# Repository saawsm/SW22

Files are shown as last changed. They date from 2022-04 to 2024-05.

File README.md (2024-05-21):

# SW22 - A modular E-Stim

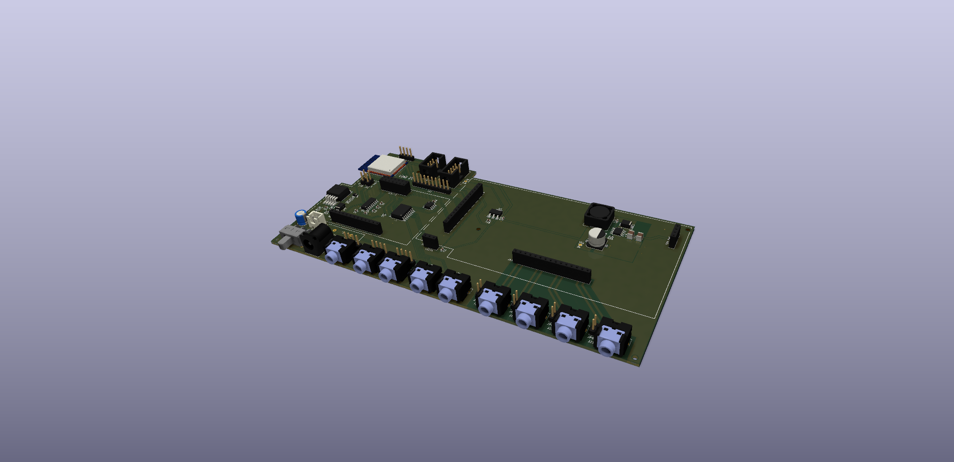
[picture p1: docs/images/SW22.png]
SW22


---
**The SW22 is deprecated. See the [SW32 E-Stim](https://github.com/saawsm/SW32) for a better alternative.**

*This project is a work in-progress. Changes to the design might occur. Order PCBs at your own risk..*

---

## About
The SW22 is a modular E-Stim box based on the [ZC95](https://github.com/CrashOverride85/zc95) and the [WT-312](https://github.com/WendyTeslaburger/WT-312). 
It has a similar form factor and output design to the MK312-BT (which in turn is a clone of the ET-312B).

An <abbr title="ESP32-WROOM-32">ESP32</abbr> module is used for high level control (front panel controls, display, Bluetooth audio, etc) of the device, while an RP2040 microcontroller (RPi Pico) is used as a co-processor for pulse/routine generation (taking advantage of [PIO](https://raspberrypi.github.io/pico-sdk-doxygen/group__hardware__pio.html#details)). The firmware is open source and written in C.

Compared to the MK312-BT, it has two extra output channels, four auxiliary inputs, and four triggers. 

## Features
* Bluetooth A2DP*
* RS232 front panel serial
* 2x TRS 3.5mm Aux channels with expansion board support (e.g. Stereo Audio + Mono Microphone, RS232 Remote)
* 2x TRS 3.5mm Trigger channels
* Tri polar (+, GND, -) output channel support
* Modular output drivers per channel (Think: Sparkfun, Adafruit, etc.) incl. modular driver board.
* Individual channel sensing via quad 12-bit ADC
* 1.8" Color TFT display
* Support for an internal 0.96" I2C OLED display (e.g. debugging/testing)
* 256kb EEPROM for configuration
* Battery voltage monitoring
* Charge sense (Barrel jack voltage monitoring)

## Overview
The SW22 consists of following PCBs:
* Front Panel Cover - No traces, just the cosmetic front panel with text. Could be 3D printed or laser cut.
* Front Panel - I2C based expansion board with 4x POTs with associated ADC, 1x rotary encoder, 4x tactile buttons, 1x buzzer, and 8x addressable RGB LEDs.
* Base Board - Provides system power, battery charging, expansion, Bluetooth, front panel interface, and general control.
* Driver Board - Provides low-level control over channel output modules.
* Output Modules - Generates the E-Stim for each channel. A module per channel, controlled by the driver board. 
* Expansion Module (Optional) - Allows advanced configuration of Aux channels (e.g. Audio+Microphone)

The main reason for having modular PCBs is for flexibility and long term cost saving. Most of the cost and time that is involved in the project is the firmware, case, display, controls, etc. So being able to reuse parts when changing the design (e.g. new output modules, driver board, etc) should help keep time and cost down.

Additionally, the SW22 was designed with the front panel and display being optional accessories. Anything that can be achieved on the front panel, can be done via Bluetooth/WiFi. The driver board can be used as a standalone module (Think: Sparkfun, Adafruit, etc.).

## Build Notes
The majority of this build is SMT. I have tried to keep parts large enough (0603 and above) for manual pick and place. However, for a few components, no alternative was available (e.g. Driver board uses MSOP/VSSOP packages).

Most SMD components used are available from Mouser and LCSC. Front panel components being mostly available at places that aren't LCSC (pots, encoders, audio jacks, etc).

Some components have a thermal pad that will require a reflow oven or using hot air reflow soldering.

## [Schematics](schematics/)

## [Gerbers](gerbers/)
Gerbers are created for use with JLCPCB. P&P POS files untested/missing (since I assemble the PCBs myself).

## Firmware
The firmware is open source and written in C. You can find the source code in the [swef](https://github.com/saawsm/swef) and [swx](https://github.com/saawsm/swx) repositories.

`swef` and `swx` don't support SPI used by the SW22 for connection between the base and driver boards. Basic functionality requires adding additional bodge wires (SDA and SCL) between the base and driver boards.

This change was done to simplify communications and to prepare for the successor [SW32](https://github.com/saawsm/SW32) box.

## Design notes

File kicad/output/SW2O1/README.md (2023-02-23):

## SW2O1 - Single Channel Output Module

This is a single channel E-Stim output module. It tries to mimic the output stage of the well-known Erostec ET312, or better, the MK-312.

The design of this module was based on the [WT-312](https://github.com/WendyTeslaburger/WT-312).

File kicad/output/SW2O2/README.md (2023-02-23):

## SW2O2 - Single Channel Output Module

A single channel E-Stim output module. It tries to mimic the output stage of the well-known Erostec ET312, or better, the MK-312.

This module is functionally the same as the SW2O1 but uses a TO-220 package for the power limiting circuit. Allowing for the use of the IRF9Z24 P-Fet used in the MK-312.

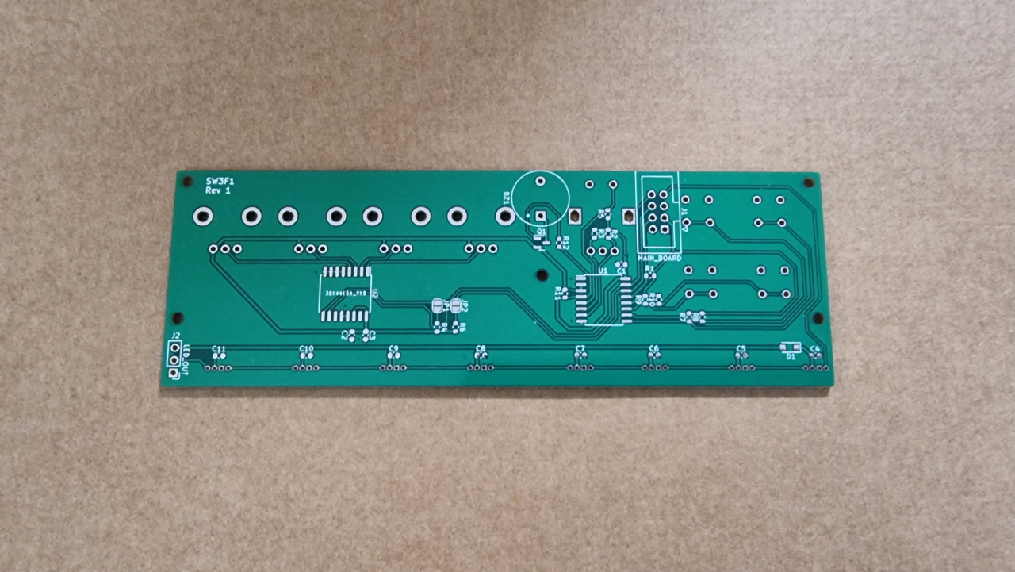
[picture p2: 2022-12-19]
docs/images/SW2F1_unpopulated_back.png

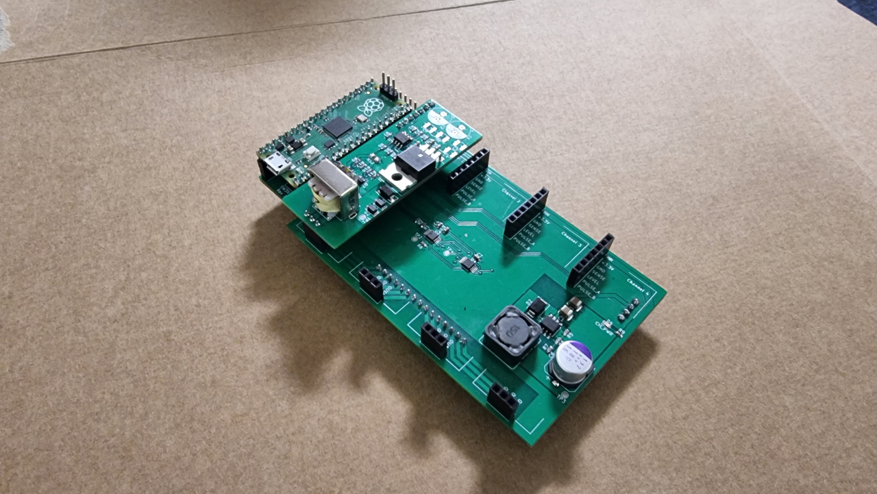
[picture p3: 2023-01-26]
docs/images/SW2X1_stacked.png

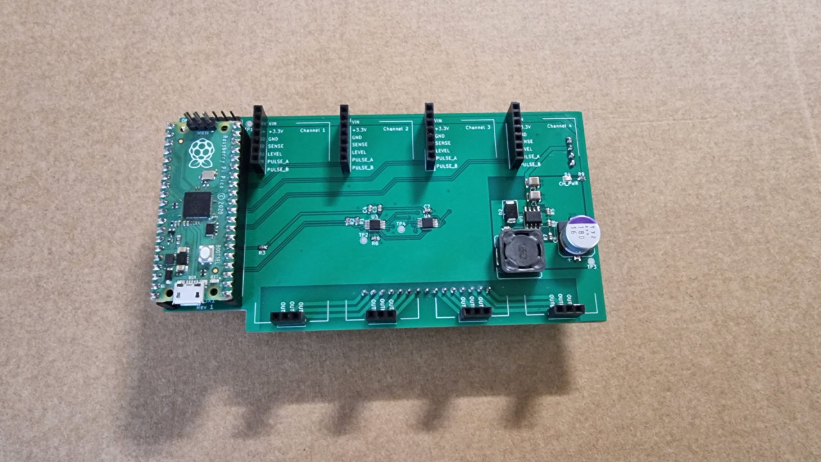
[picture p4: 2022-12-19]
docs/images/SW2X1_populated_pico.png

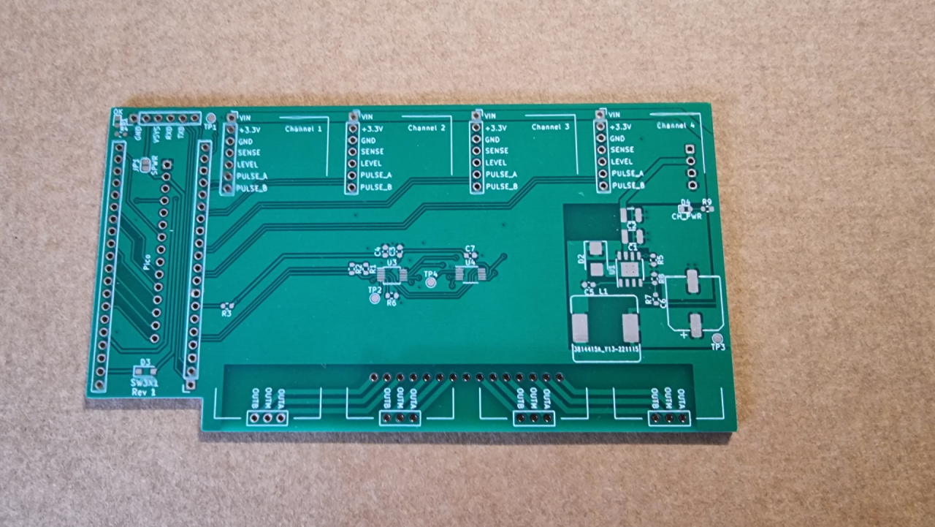
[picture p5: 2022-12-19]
docs/images/SW2X1_unpopulated.png

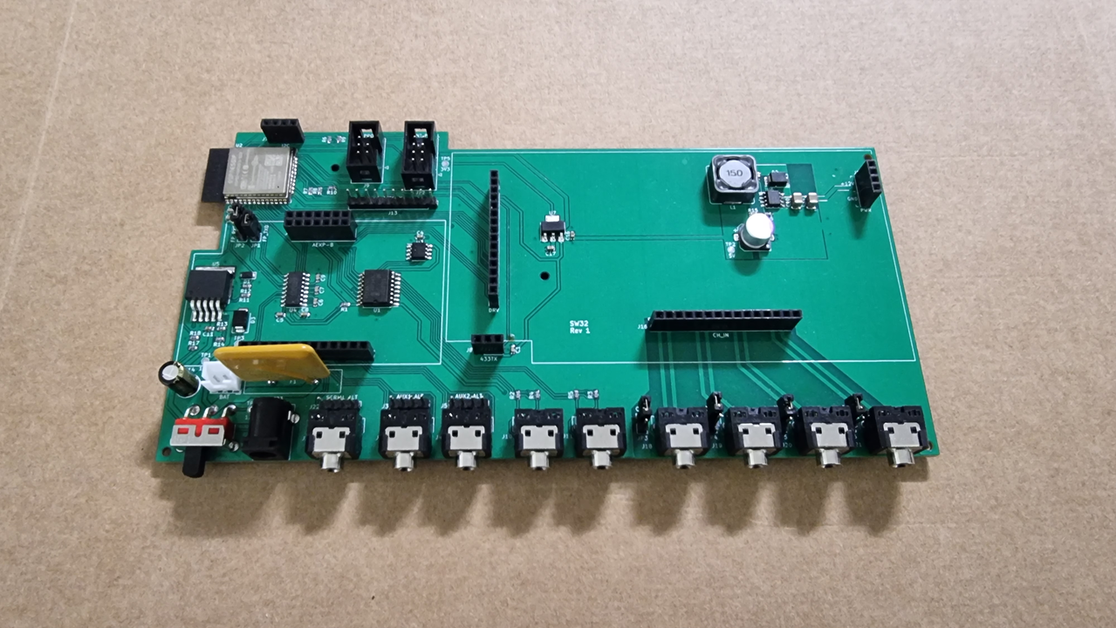
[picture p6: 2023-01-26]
docs/images/SW22_populated.png

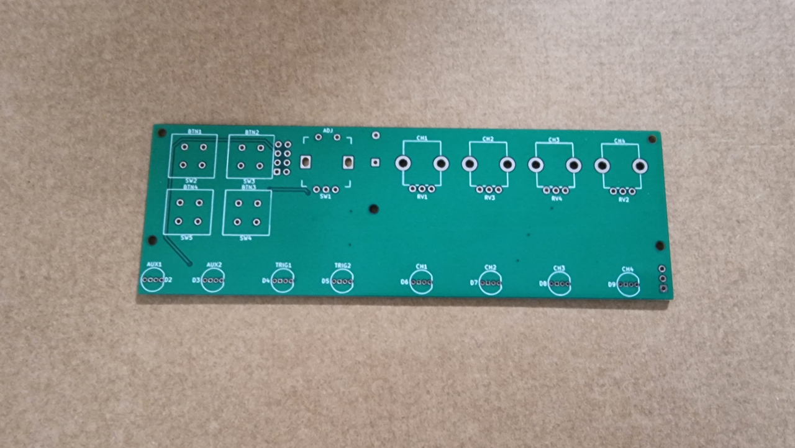
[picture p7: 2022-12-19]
docs/images/SW2F1_unpopulated_front.png

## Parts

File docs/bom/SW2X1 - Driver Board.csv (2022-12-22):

Ref | Qty | Value | Description | MPN | MOUSER | LCSC
C1, C2 | 2 | 10uF | Unpolarized capacitor | CL32A106KBJNNNE | 187-CL32A106KBJNNNE | C380537
C3 | 1 | 10uF | Unpolarized capacitor, small symbol | CL10A106MA8NRNC | 187-CL10A106MA8NRNC | C96446
C4, C7 | 2 | 100nF | Unpolarized capacitor, small symbol | CL10B104KB8NNNC | 187-CL10B104KB8NNNC | C1591
C5 | 1 | 10nF | Unpolarized capacitor | CL10B103KB8NNNC | 187-CL10B103KB8NNNC | C1589
C6 | 1 | 180uF | Polarized capacitor | 16SVP180MX | 667-16SVP180MX | C236288
D1 | 1 | OK | Light emitting diode | 150060VS75000 | 710-150060VS75000
D2 | 1 | SSB44-E3 | Schottky diode | SSB44-E3/52T | 625-SSB44-E3 | C466999
D3 | 1 | SS24FL | Schottky diode | SS24FL | 512-SS24FL | C894433
D4 | 1 | CH_PWR | Light emitting diode | 150060BS75000 | 710-150060BS75000
J1 | 1 | SERIAL (3v3) | Generic connector, single row, 01x06, script generated (kicad-library-utils/schlib/autogen/connector/)
J2 | 1 | PWR | Generic connector, single row, 01x04, script generated (kicad-library-utils/schlib/autogen/connector/)
J3 | 1 | CONTROL | Generic connector, single row, 01x15, script generated (kicad-library-utils/schlib/autogen/connector/)
J4 | 1 | Channel 1 | Dual Channel Output Driver Module
J5 | 1 | Channel 2 | Dual Channel Output Driver Module
J6 | 1 | Channel 3 | Dual Channel Output Driver Module
J7 | 1 | Channel 4 | Dual Channel Output Driver Module
J8 | 1 | CH_OUT | Generic connector, single row, 01x15, script generated (kicad-library-utils/schlib/autogen/connector/)
L1 | 1 | 15uH | Inductor with ferrite core | SRR1260-150M | 652-SRR1260-150M | C2041333
R1, R2, R9 | 3 | 4.7K | Resistor | RC0603FR-074K7L | 603-RC0603FR-074K7L | C99782
R3, R6, R7 | 3 | 10K | Resistor | RC0603FR-0710KL | 603-RC0603FR-0710KL | C98220
R4, R8 | 2 | 1.5K | Resistor | RC0603FR-071K5L | 603-RC0603FR-071K5L | C114668
R5 | 1 | 100K | Resistor | RC0603FR-07100KL | 603-RC0603FR-07100KL | C14675
U1 | 1 | TPS5430DDA | 3A, Step Down Swift Converter, Adjustable Output Voltage, 5.5-36V Input Voltage, PowerSO-8 | TPS5430DDAR | 595-TPS5430DDAR | C9864
U2 | 1 | Pico |  | RASPBERRY PI PICO (UNSOLDERED) | 713-102110537
U3 | 1 | MCP4728 | 12-bit digital to analog converter, quad output, 2.048V internal reference, integrated EEPROM, I2C interface | MCP4728-E/UN | 579-MCP4728-E/UN | C108207
U4 | 1 | ADS1015 | Ultra-Small, Low-Power, I2C-Compatible, 3.3-kSPS, 12-Bit ADCs With Internal Reference, Oscillator, and Programmable Comparator, VSSOP-10 | ADS1015IDGSR | 595-ADS1015IDGSR | C193969

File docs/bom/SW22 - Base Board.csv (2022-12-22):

Ref | Qty | Value | Description | MPN | MOUSER | LCSC
C1, C3, C4, C5, C6, C7, C8, C9, C18 | 9 | 100nF | Unpolarized capacitor, small symbol | CL10B104KB8NNNC | 187-CL10B104KB8NNNC | C1591
C2, C16, C17 | 3 | 10uF | Unpolarized capacitor | CL10A106MA8NRNC | 187-CL10A106MA8NRNC | C96446
C10, C12 | 2 | 10uF | Unpolarized capacitor | CL32A106KBJNNNE | 187-CL32A106KBJNNNE | C380537
C11 | 1 | 470nF | Unpolarized capacitor | CL10A474KB8NNNC | 187-CL10A474KB8NNNC | C170149
C13 | 1 | 10nF | Unpolarized capacitor | CL10B103KB8NNNC | 187-CL10B103KB8NNNC | C1589
C14 | 1 | 100uF | Polarized capacitor | EEU-FM1E101 | 667-EEU-FM1E101 | C1579509
C15 | 1 | 270uF | Polarized capacitor | 16SVPF270M | 667-16SVPF270M | C136278
D1 | 1 | SS24FL | Schottky diode | SS24FL | 512-SS24FL | C894433
D2, D3 | 2 | SSB44-E3 | Schottky diode | SSB44-E3/52T | 625-SSB44-E3 | C466999
D4 | 1 | PWR | Light emitting diode | 150060VS75000 | 710-150060VS75000
F1 | 1 | 2A | Resettable fuse, polymeric positive temperature coefficient | LVR200S-240 | 650-LVR200S-240 | C1562345
J1 | 1 | AEXP-B | Generic connector, double row, 02x07, odd/even pin numbering scheme (row 1 odd numbers, row 2 even numbers), script generated (kicad-library-utils/schlib/autogen/connector/)
J2 | 1 | AUX1 | Audio Jack, 3 Poles (Stereo / TRS), Switched TR Poles (Normalling) | STX-3100-5N | 806-STX-3100-5N
J3 | 1 | AUX1_ALT | Generic connector, single row, 01x04, script generated (kicad-library-utils/schlib/autogen/connector/)
J4 | 1 | AUX2 | Audio Jack, 3 Poles (Stereo / TRS), Switched TR Poles (Normalling) | STX-3100-5N | 806-STX-3100-5N
J5 | 1 | AUX2_ALT | Generic connector, single row, 01x04, script generated (kicad-library-utils/schlib/autogen/connector/)
J6 | 1 | AEXP-A | Generic connector, single row, 01x13, script generated (kicad-library-utils/schlib/autogen/connector/)
J7 | 1 | I2C | Generic connector, single row, 01x04, script generated (kicad-library-utils/schlib/autogen/connector/)
J8 | 1 | 433TX | Generic connector, single row, 01x03, script generated (kicad-library-utils/schlib/autogen/connector/)
J9 | 1 | PROG | Generic connector, double row, 02x03, odd/even pin numbering scheme (row 1 odd numbers, row 2 even numbers), script generated (kicad-library-utils/schlib/autogen/connector/)
J10 | 1 | TRG1 | Audio Jack, 3 Poles (Stereo / TRS), Switched TR Poles (Normalling) | STX-3100-5N | 806-STX-3100-5N
J11 | 1 | TRG2 | Audio Jack, 3 Poles (Stereo / TRS), Switched TR Poles (Normalling) | STX-3100-5N | 806-STX-3100-5N
J12 | 1 | FRONT_PANEL | Generic connector, double row, 02x04, odd/even pin numbering scheme (row 1 odd numbers, row 2 even numbers), script generated (kicad-library-utils/schlib/autogen/connector/)
J13 | 1 | DISPLAY | Generic connector, single row, 01x10, script generated (kicad-library-utils/schlib/autogen/connector/)
J14 | 1 | DRV | Generic connector, single row, 01x15, script generated (kicad-library-utils/schlib/autogen/connector/)
J15 | 1 | PWR | Generic connector, single row, 01x04, script generated (kicad-library-utils/schlib/autogen/connector/)
J16 | 1 | CH_IN | Generic connector, single row, 01x15, script generated (kicad-library-utils/schlib/autogen/connector/)
J17 | 1 | SERIAL | Audio Jack, 3 Poles (Stereo / TRS), Switched TR Poles (Normalling) | STX-3100-5N | 806-STX-3100-5N
J18 | 1 | CH1 | Audio Jack, 3 Poles (Stereo / TRS), Switched TR Poles (Normalling) | STX-3100-5N | 806-STX-3100-5N
J19 | 1 | CH2 | Audio Jack, 3 Poles (Stereo / TRS), Switched TR Poles (Normalling) | STX-3100-5N | 806-STX-3100-5N
J20 | 1 | CH3 | Audio Jack, 3 Poles (Stereo / TRS), Switched TR Poles (Normalling) | STX-3100-5N | 806-STX-3100-5N
J21 | 1 | CH4 | Audio Jack, 3 Poles (Stereo / TRS), Switched TR Poles (Normalling) | STX-3100-5N | 806-STX-3100-5N
J22 | 1 | SERIAL_ALT | Generic connector, single row, 01x04, script generated (kicad-library-utils/schlib/autogen/connector/)
J23 | 1 | PWR | DC Barrel Jack with an internal switch | PJ-102AH | 490-PJ-102AH
J24 | 1 | BAT | Generic screw terminal, single row, 01x02, script generated (kicad-library-utils/schlib/autogen/connector/)
JP1 | 1 | FP_TXD | Jumper, 2-pole, closed/bridged
JP2 | 1 | FP_RXD | Jumper, 2-pole, closed/bridged
JP3 | 1 | CT1 | Jumper, 2-pole, open
JP4 | 1 | CT2 | Jumper, 2-pole, open
JP5 | 1 | CT3 | Jumper, 2-pole, open
JP6 | 1 | CT4 | Jumper, 2-pole, open
L1 | 1 | 15uH | Inductor with ferrite core | SRR1260-150M | 652-SRR1260-150M | C2041333
R1, R2, R3, R4, R5, R7, R8, R10, R12, R13, R15, R19 | 12 | 10K | Resistor, small symbol | RC0603FR-0710KL | 603-RC0603FR-0710KL | C98220
R6, R9, R18 | 3 | 4.7K | Resistor | RC0603FR-074K7L | 603-RC0603FR-074K7L | C99782
R11 | 1 | 100K | Resistor | RC0603FR-07100KL | 603-RC0603FR-07100KL | C14675
R14 | 1 | 1K | Resistor | RC0603FR-071KL | 603-RC0603FR-071KL | C22548
R16 | 1 | 3.24K | Resistor | RC0603FR-073K24L | 603-RC0603FR-073K24L | C273779
R17 | 1 | 27K | Resistor | RC0603FR-0727KL | 603-RC0603FR-0727KL | C114614
R20 | 1 | 1.5k | Resistor | RC0603FR-071K5L | 603-RC0603FR-071K5L | C114668
SW1 | 1 | PWR | Switch, single pole double throw | 500SSP1S2M6QEA | 612-500-A261
U1 | 1 | PCF8574 | 8 Bit Port/Expander to I2C Bus, DIP/SOIC-16 | PCF8574T/3,512 | 771-PCF85T3512 | C1522621
U2 | 1 | ESP32-WROOM-32D | RF Module, ESP32-D0WD SoC, Wi-Fi 802.11b/g/n, Bluetooth, BLE, 32-bit, 2.7-3.6V, onboard antenna, SMD | ESP32-WROOM-32D-N16
U3 | 1 | CAT24C256 | 256 kb CMOS Serial EEPROM, DIP-8/SOIC-8/TSSOP-8/DFN-8 | CAT24C256WI-GT3 | 698-CAT24C256WI-GT3 | C79987
U4 | 1 | SP3232 | Dual RS232 driver/receiver, 5V supply, 120kb/s, 0C-70C | SP3232EEN-L/TR | 701-SP3232EEN-L/TR | C9378
U5 | 1 | LM2941 | LM2941x 1-A Low Dropout Adjustable Regulator | LM2941CSX/NOPB | 926-LM2941CSX/NOPB | C512759
U6 | 1 | TPS5430DDA | 3A, Step Down Swift Converter, Adjustable Output Voltage, 5.5-36V Input Voltage, PowerSO-8 | TPS5430DDAR | 595-TPS5430DDAR | C9864
U7 | 1 | NCP1117LP | 1A Low drop-out regulator, Fixed Output 3.3V, SOT-223 | NCP1117LPST33T3G | 863-NCP1117LPST33T3G | C146799

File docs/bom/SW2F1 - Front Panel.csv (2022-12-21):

Ref | Qty | Value | Description | MPN | MOUSER | LCSC
BZ1 | 1 | Buzzer | Buzzer, polarized | IE122303-1 | 497-IE122303-1
C1, C2, C4, C5, C6, C7, C8, C9, C10, C11 | 10 | 100nF | Unpolarized capacitor, small symbol | CL10B104KB8NNNC | 187-CL10B104KB8NNNC | C1591
C3 | 1 | 10uF | Unpolarized capacitor, small symbol | CL10A106MA8NRNC | 187-CL10A106MA8NRNC | C96446
D1 | 1 | SS24FL | Schottky diode | SS24FL | 512-SS24FL | C894433
D2 | 1 | AUX1 |  | WS2812D-F5 |  | C190565
D3 | 1 | AUX2 |  | WS2812D-F5 |  | C190565
D4 | 1 | TRIG1 |  | WS2812D-F5 |  | C190565
D5 | 1 | TRIG2 |  | WS2812D-F5 |  | C190565
D6 | 1 | CH1 |  | WS2812D-F5 |  | C190565
D7 | 1 | CH2 |  | WS2812D-F5 |  | C190565
D8 | 1 | CH3 |  | WS2812D-F5 |  | C190565
D9 | 1 | CH4 |  | WS2812D-F5 |  | C190565
J1 | 1 | MAIN_BOARD | Generic connector, double row, 02x04, odd/even pin numbering scheme (row 1 odd numbers, row 2 even numbers), script generated (kicad-library-utils/schlib/autogen/connector/)
Q1 | 1 | DMG2301L-7 | P-MOSFET transistor, gate/source/drain | DMG2301L-7 | 621-DMG2301L-7 | C102619
R1, R2, R3, R4, R5, R6, R7, R8, R9, R10, R11 | 11 | 10K | Resistor, small symbol | RC0603FR-0710KL | 603-RC0603FR-0710KL | C98220
R12 | 1 | 100 | Resistor, small symbol | RC0603FR-07100RL | 603-RC0603FR-07100RL | C105588
RV1 | 1 | CH1 | Potentiometer | PTV09A-4020S-B103
RV2 | 1 | CH4 | Potentiometer | PTV09A-4020S-B103
RV3 | 1 | CH2 | Potentiometer | PTV09A-4020S-B103
RV4 | 1 | CH3 | Potentiometer | PTV09A-4020S-B103
SW1 | 1 | PEC11R-4215K-S0024 | Rotary encoder, dual channel, incremental quadrate outputs, with switch | PEC11R-4215K-S0024
SW2 | 1 | BTN1 | Push button switch, generic, two pins | D6C90F2LFS | 611-D6C90F2LFS
SW3 | 1 | BTN2 | Push button switch, generic, two pins | D6C90F2LFS | 611-D6C90F2LFS
SW4 | 1 | BTN3 | Push button switch, generic, two pins | D6C90F2LFS | 611-D6C90F2LFS
SW5 | 1 | BTN4 | Push button switch, generic, two pins | D6C90F2LFS | 611-D6C90F2LFS
U1 | 1 | PCF8574 | 8 Bit Port/Expander to I2C Bus, DIP/SOIC-16 | PCF8574T/3,512 | 771-PCF85T3512 | C1522621
U2 | 1 | PCF8591 | 4ch ADC, 1 DAC, I2C Bus Interface, DIP/SOIC-16 | PCF8591T/2,518 | 771-PCF8591TD-T | C8366

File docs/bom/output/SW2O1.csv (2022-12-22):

Ref | Qty | Value | Description | MPN | MOUSER | LCSC
C1, C2 | 2 | 470uF | Polarized capacitor, US symbol | 477CKE016M
C3, C4, C6, C7 | 4 | 22uF | Unpolarized capacitor | CL32A226KAJNNNE
C5, C9 | 2 | 100nF | Unpolarized capacitor | CL10B104KB8NNWC
C8 | 1 | 1uF | Unpolarized capacitor | CL10B105KA8NFNC
D1 | 1 | SML4746-E3/61 | Zener diode | SML4746-E3/61
D2, D3 | 2 | SS24FL | Schottky diode | SS24FL | 512-SS24FL | C894433
FB1 | 1 | 100 | Ferrite bead, small symbol | BLM18KG101TN1D
Q1 | 1 | NTF2955T1G | P-MOSFET transistor, gate/drain/source | NTF2955T1G
Q2, Q3 | 2 | DMN2041L | 6.4A Id, 20V Vds, N-Channel MOSFET, SOT-23 | DMN2041L
R1, R5, R6 | 3 | 10k | Resistor | RC0603FR-0710KL
R2, R9, R10 | 3 | 10K | Resistor | RC0603FR-0710KL
R3 | 1 | 2K | Resistor | RC0603FR-072KL
R4 | 1 | 1K | Resistor | RC0603FR-071KL
R7, R8 | 2 | 100K | Resistor | RC0603FR-07100KL
R11, R12 | 2 | 100 | Resistor | RC0603FR-07100RL
R13 | 1 | 0.1 | Resistor | ERJ-8BWFR100V
T1 | 1 | 42TL004-RC |  | 42TL004-RC
U2 | 1 | LM358ADT | Dual CMOS Rail-to-Rail Input and Output Operational Amplifier, DIP-8/SOIC-8, SSOP-8 | LM358ADT

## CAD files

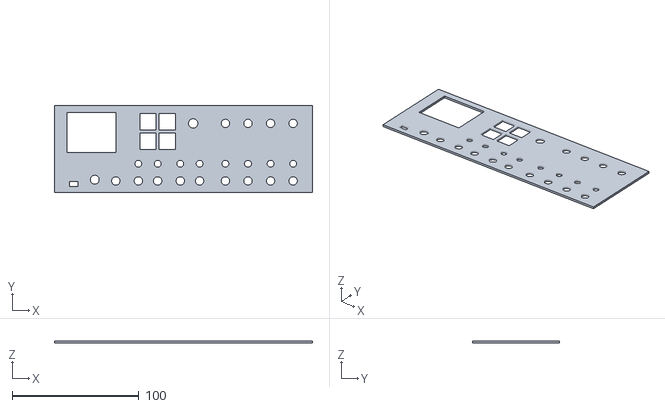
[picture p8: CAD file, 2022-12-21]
misc/SW2C1 - Front Cover.stl
203.2 x 68.6 x 1.60

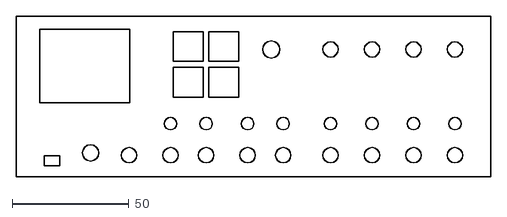
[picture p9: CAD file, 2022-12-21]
misc/SW2C1 - Front Cover-Edge_Cuts.dxf
203.2 x 68.6

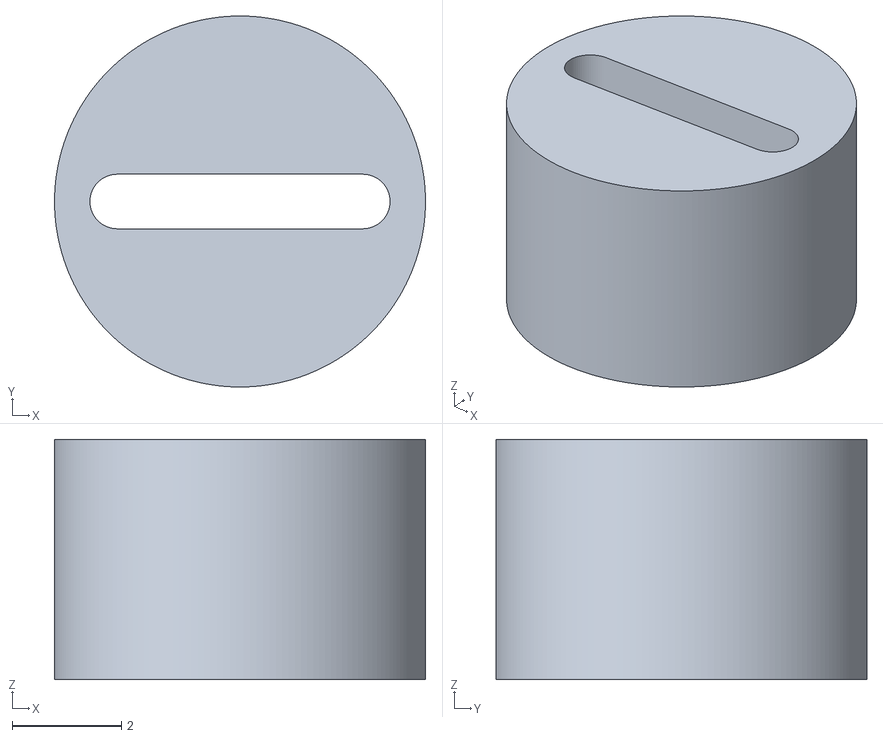
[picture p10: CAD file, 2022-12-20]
misc/6x4mm_4-pin_led_spacer.stl
6.80 x 6.80 x 4.40

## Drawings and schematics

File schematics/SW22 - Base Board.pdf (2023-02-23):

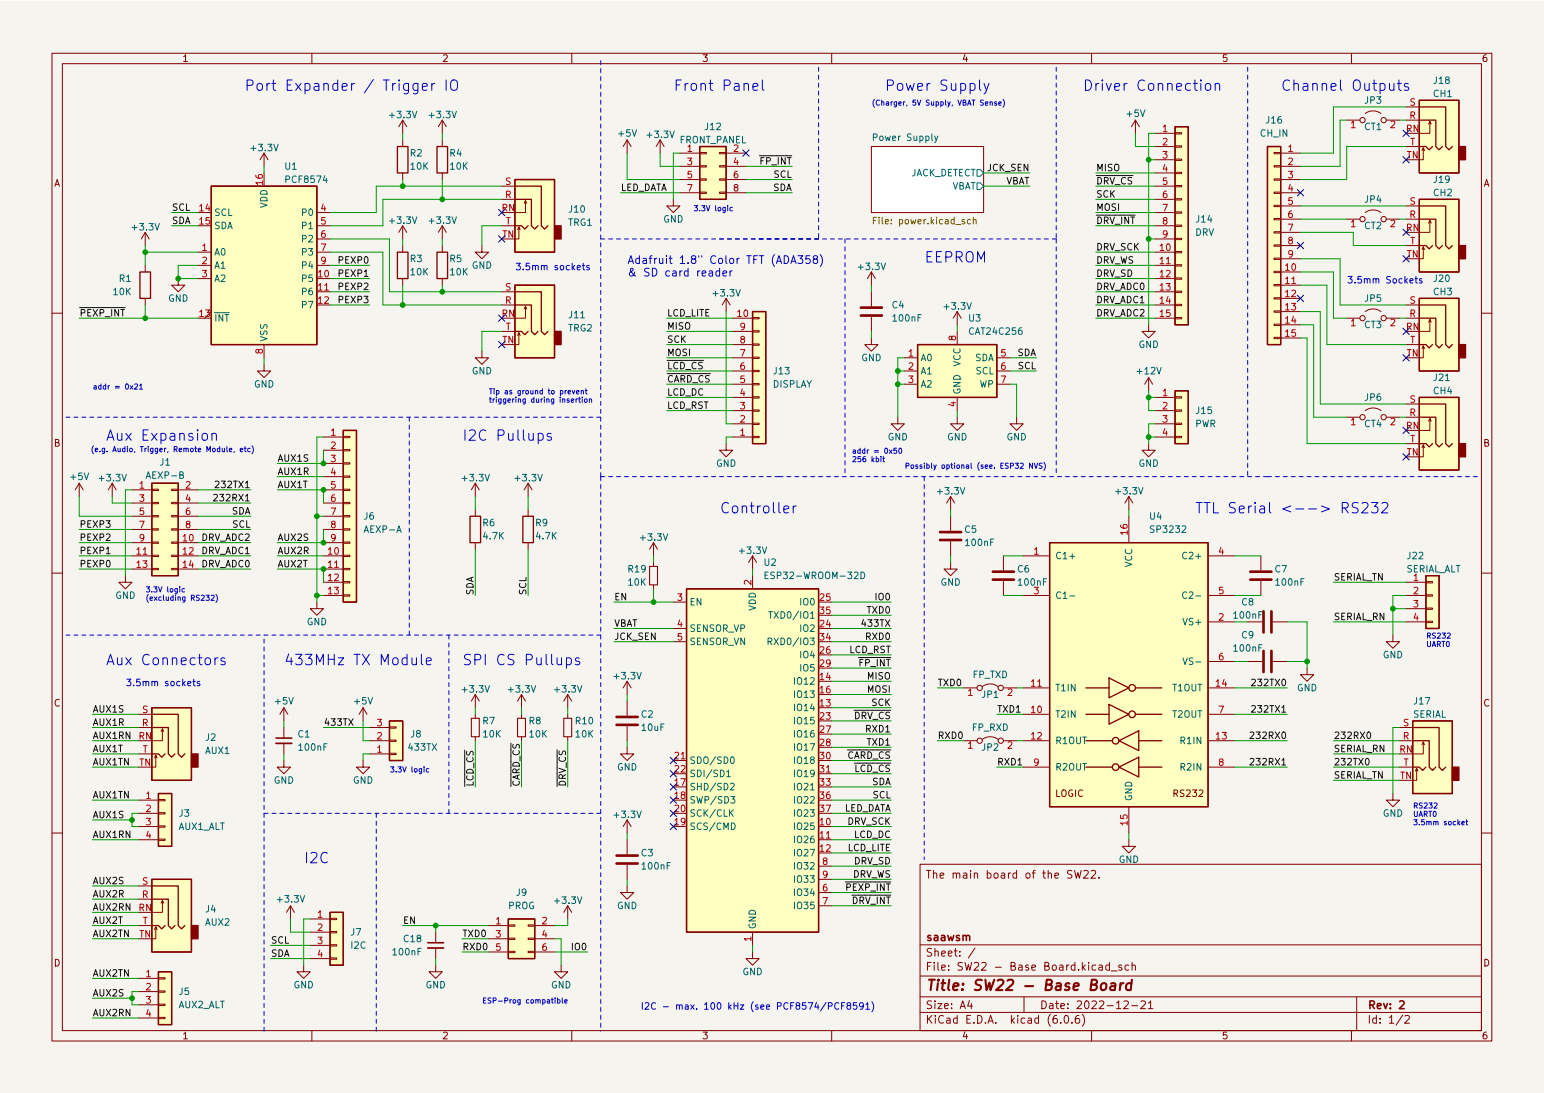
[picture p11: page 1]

(Charger, 5V Supply, VBAT Sense) Tip as ground to prevent

4 SDA 5 SCL 6 WP 7 VCC

triggering during insertion
I2C Pullups
256 kbit SPI CS Pullups

ESP-Prog compatible Aux Expansion

2 SCK/CLK 20 SDO/SD0 21 SDI/SD1 22

The main board of the SW22.

File: SW22 - Base Board.kicad_sch Sheet: / saawsm

Id: 1/2 Title: SW22 - Base Board

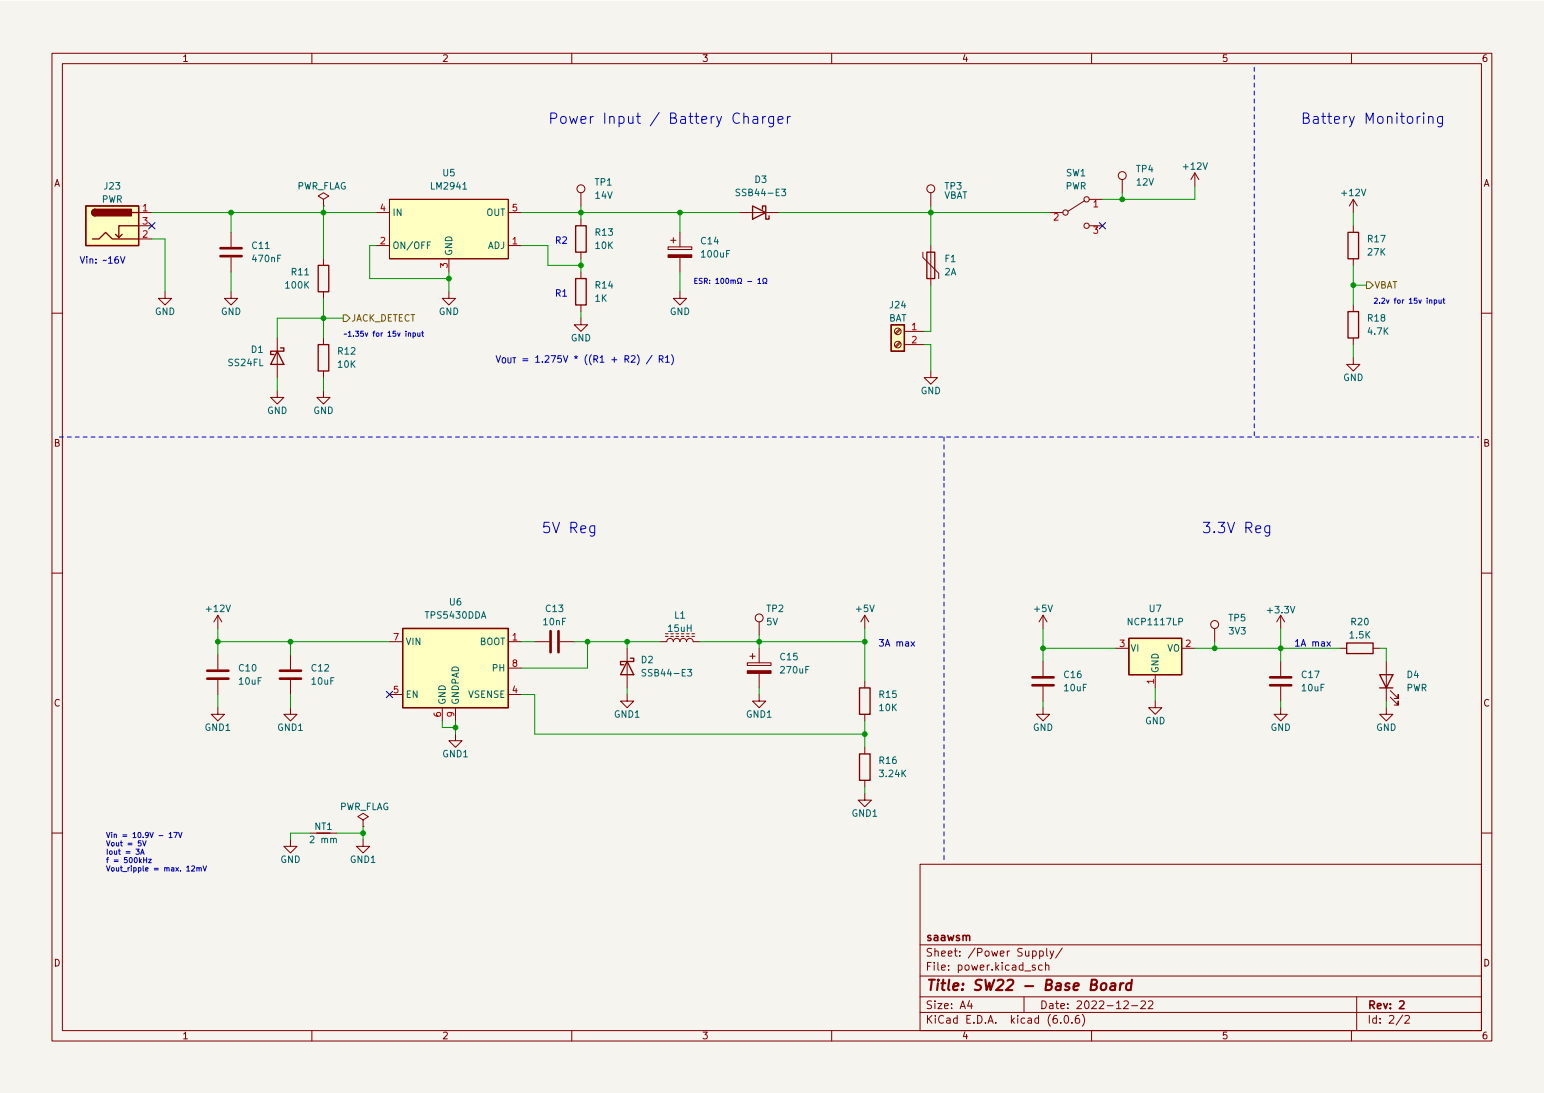
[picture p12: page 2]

3A max Power Input / Battery Charger

Sheet: /Power Supply/ saawsm

File: power.kicad_sch
Id: 2/2 Title: SW22 - Base Board

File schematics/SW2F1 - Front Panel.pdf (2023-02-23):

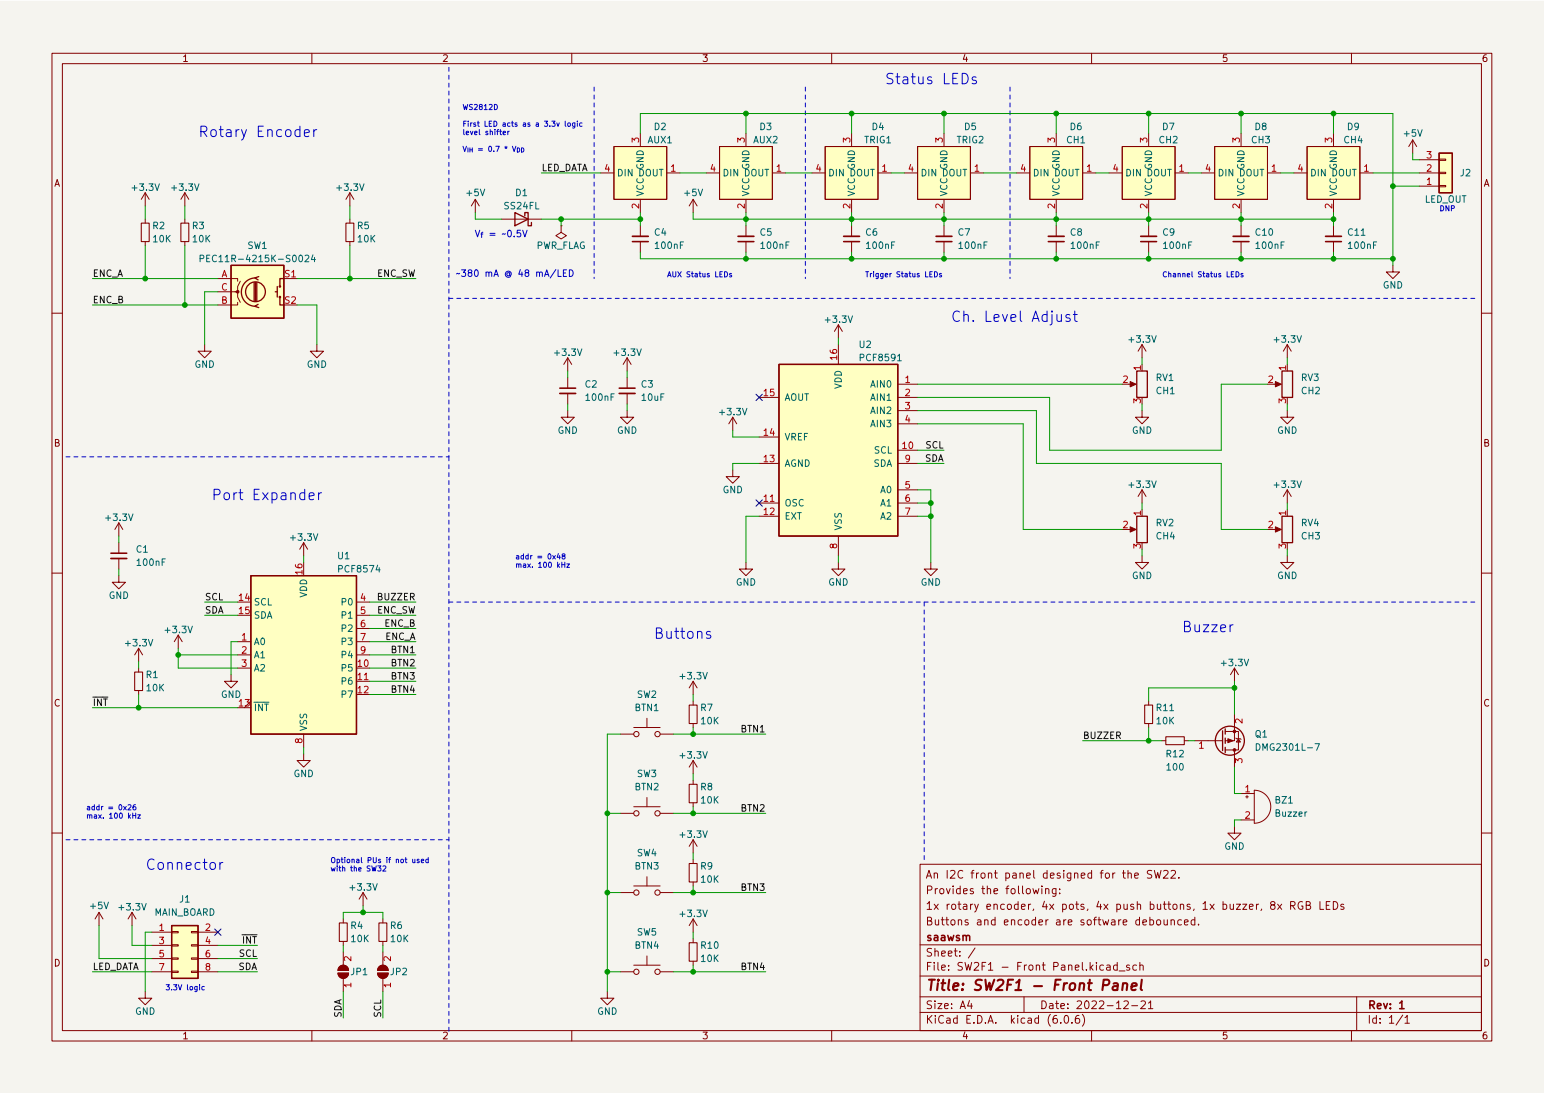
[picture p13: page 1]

Trigger Status LEDs Status LEDs
LED_OUT GND

First LED acts as a 3.3v logic

An I2C front panel designed for the SW22. GND

Provides the following:
Buttons and encoder are software debounced. 1x rotary encoder, 4x pots, 4x push buttons, 1x buzzer, 8x RGB LEDs

File: SW2F1 - Front Panel.kicad_sch Sheet: / saawsm

Id: 1/1 Title: SW2F1 - Front Panel

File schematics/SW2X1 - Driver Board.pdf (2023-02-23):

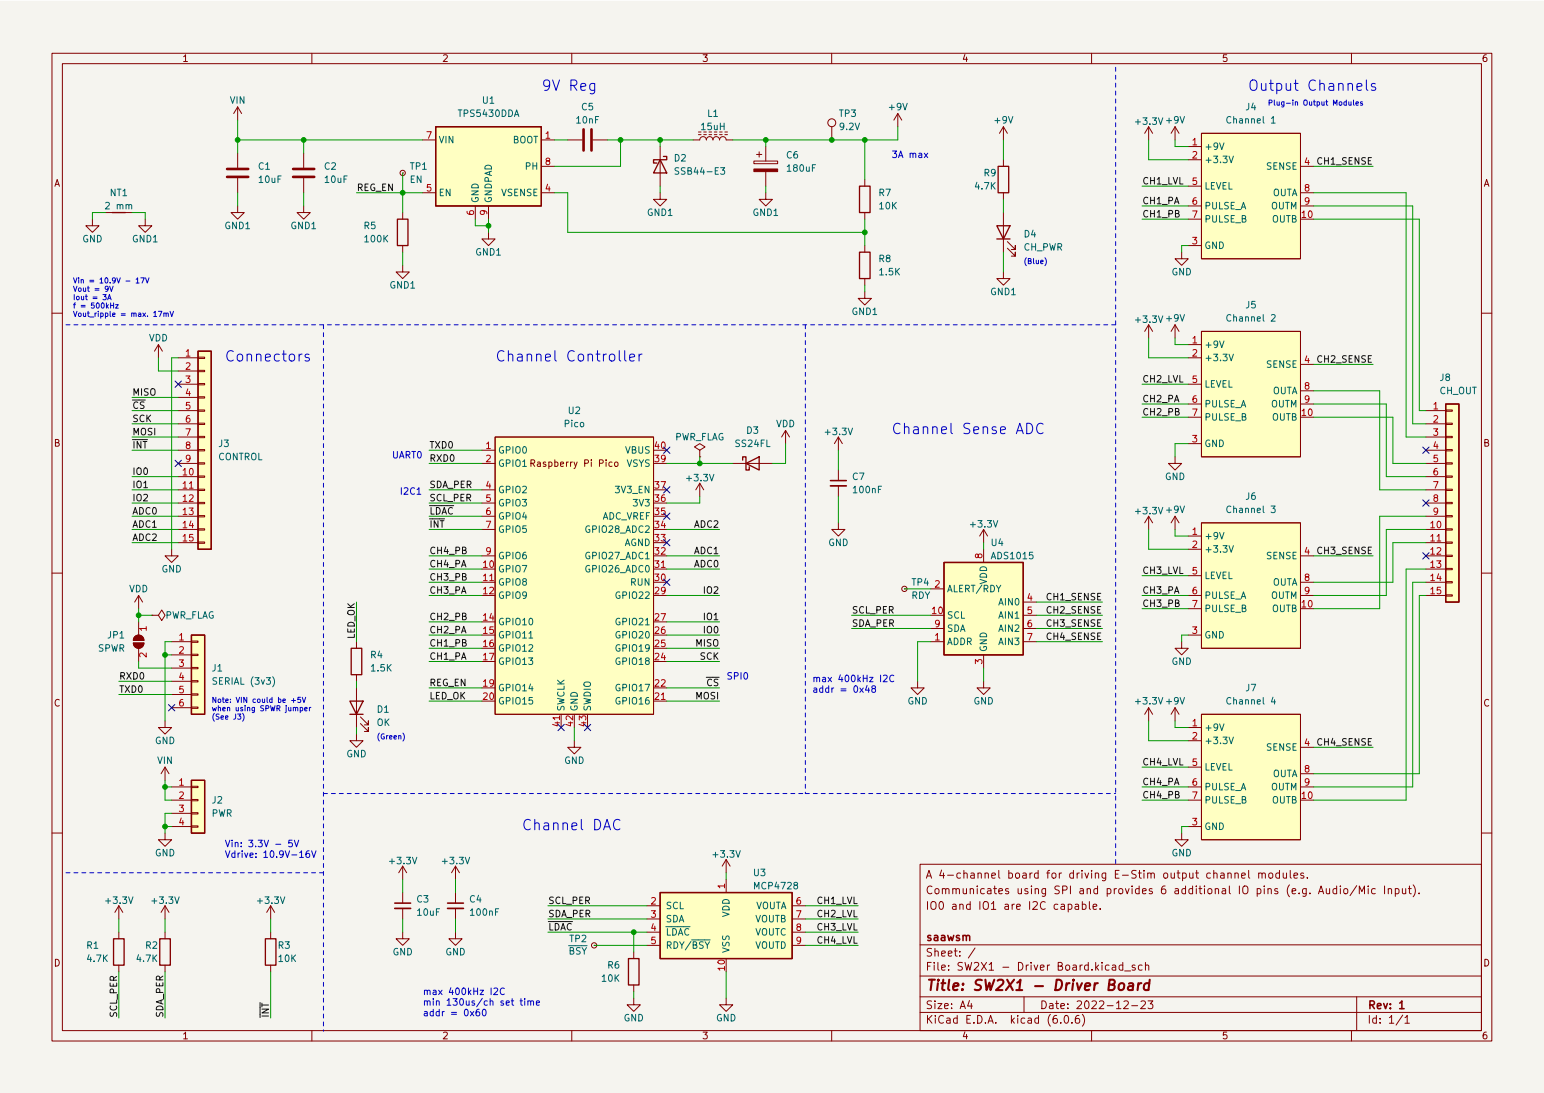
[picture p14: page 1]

Plug-in Output Modules

(Blue) Channel Sense ADC

Note: VIN could be +5V when using SPWR jumper

A 4-channel board for driving E-Stim output channel modules. GND

1 VSS 10 SCL 2 SDA 3 ~{LDAC} 4 RDY/~{BSY} 5 VOUTA 6 VOUTB 7 VOUTC 8 VOUTD 9 U3MCP4728 GND

Communicates using SPI and provides 6 additional IO pins (e.g. Audio/Mic Input).
IO0 and IO1 are I2C capable.

File: SW2X1 - Driver Board.kicad_sch Sheet: / saawsm

Id: 1/1 Title: SW2X1 - Driver Board

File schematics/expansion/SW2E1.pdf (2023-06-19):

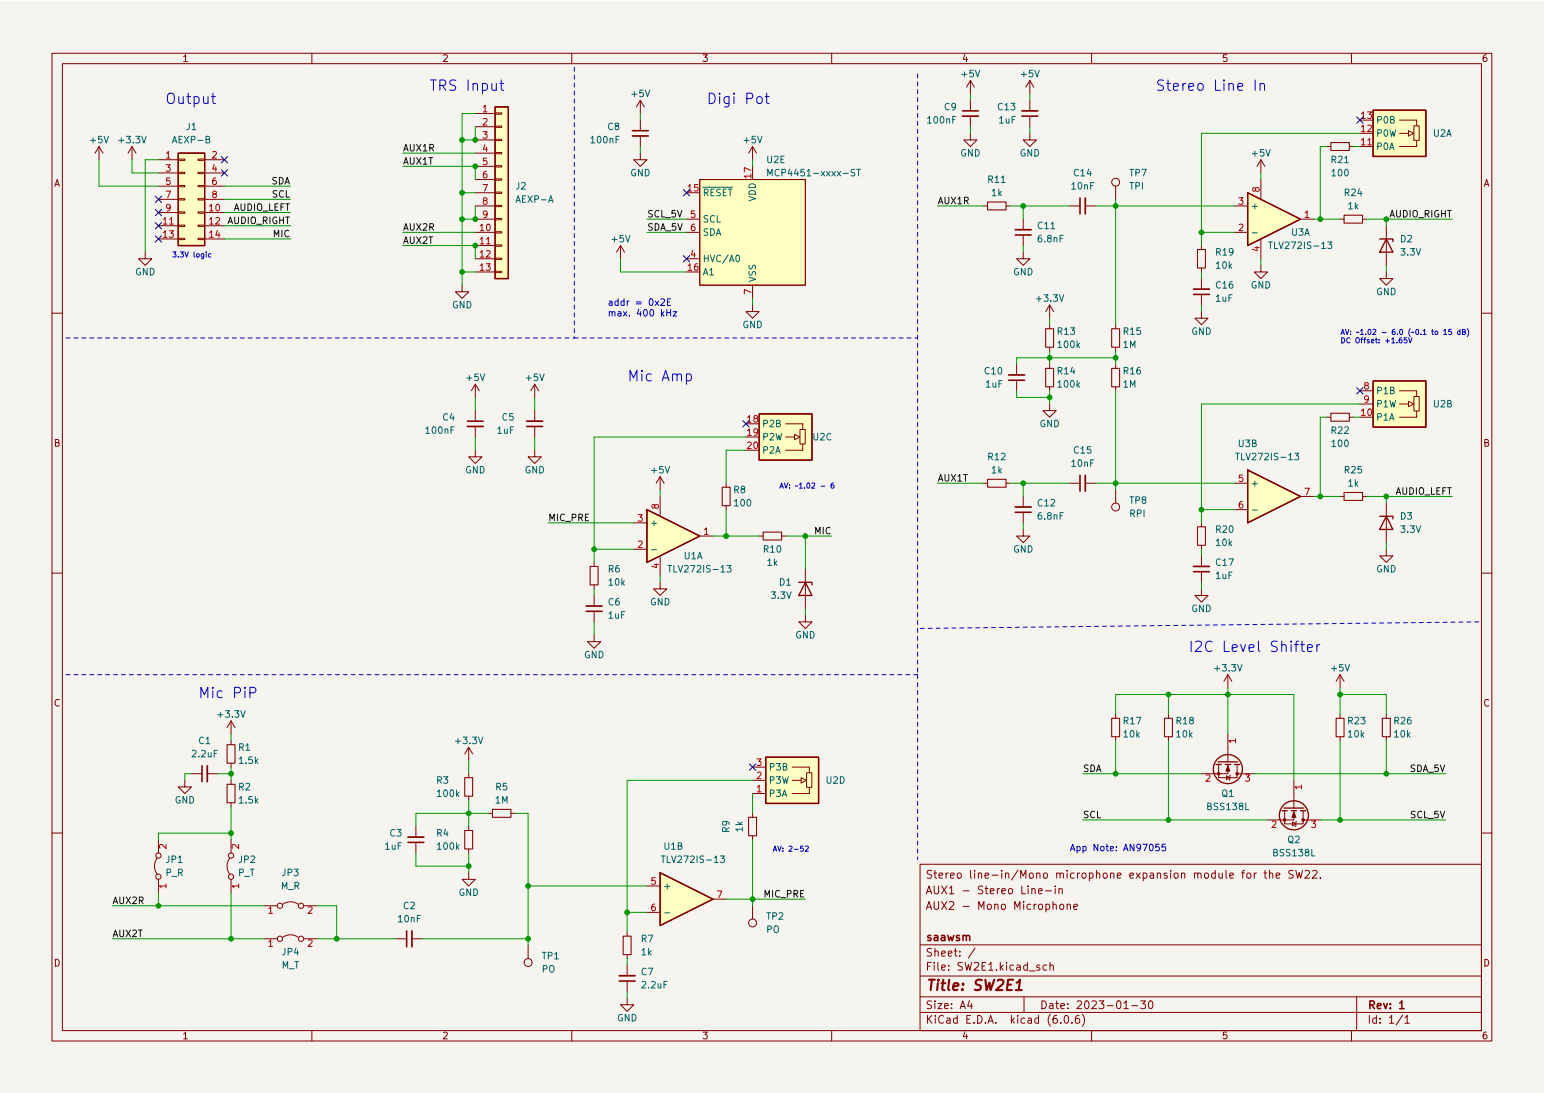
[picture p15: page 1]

AV: ~1.02 - 6.0 (~0.1 to 15 dB) DC Offset: +1.65V App Note: AN97055

AUX2 - Mono Microphone AUX1 - Stereo Line-in Stereo line-in/Mono microphone expansion module for the SW22.

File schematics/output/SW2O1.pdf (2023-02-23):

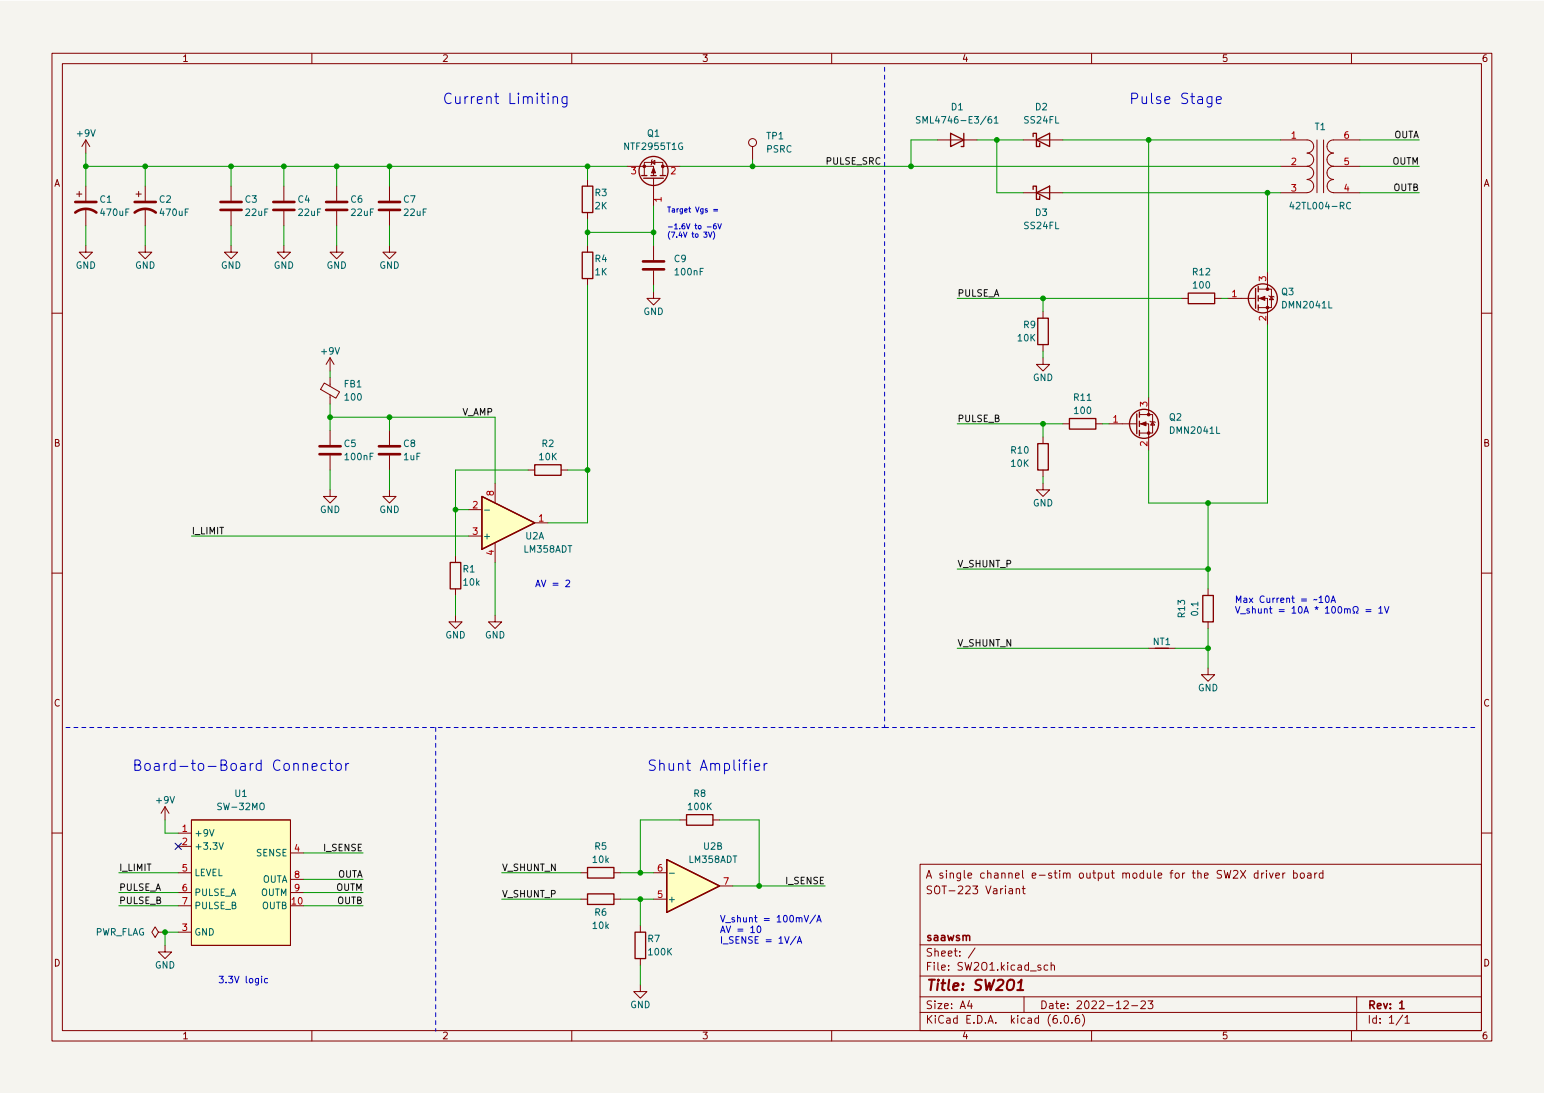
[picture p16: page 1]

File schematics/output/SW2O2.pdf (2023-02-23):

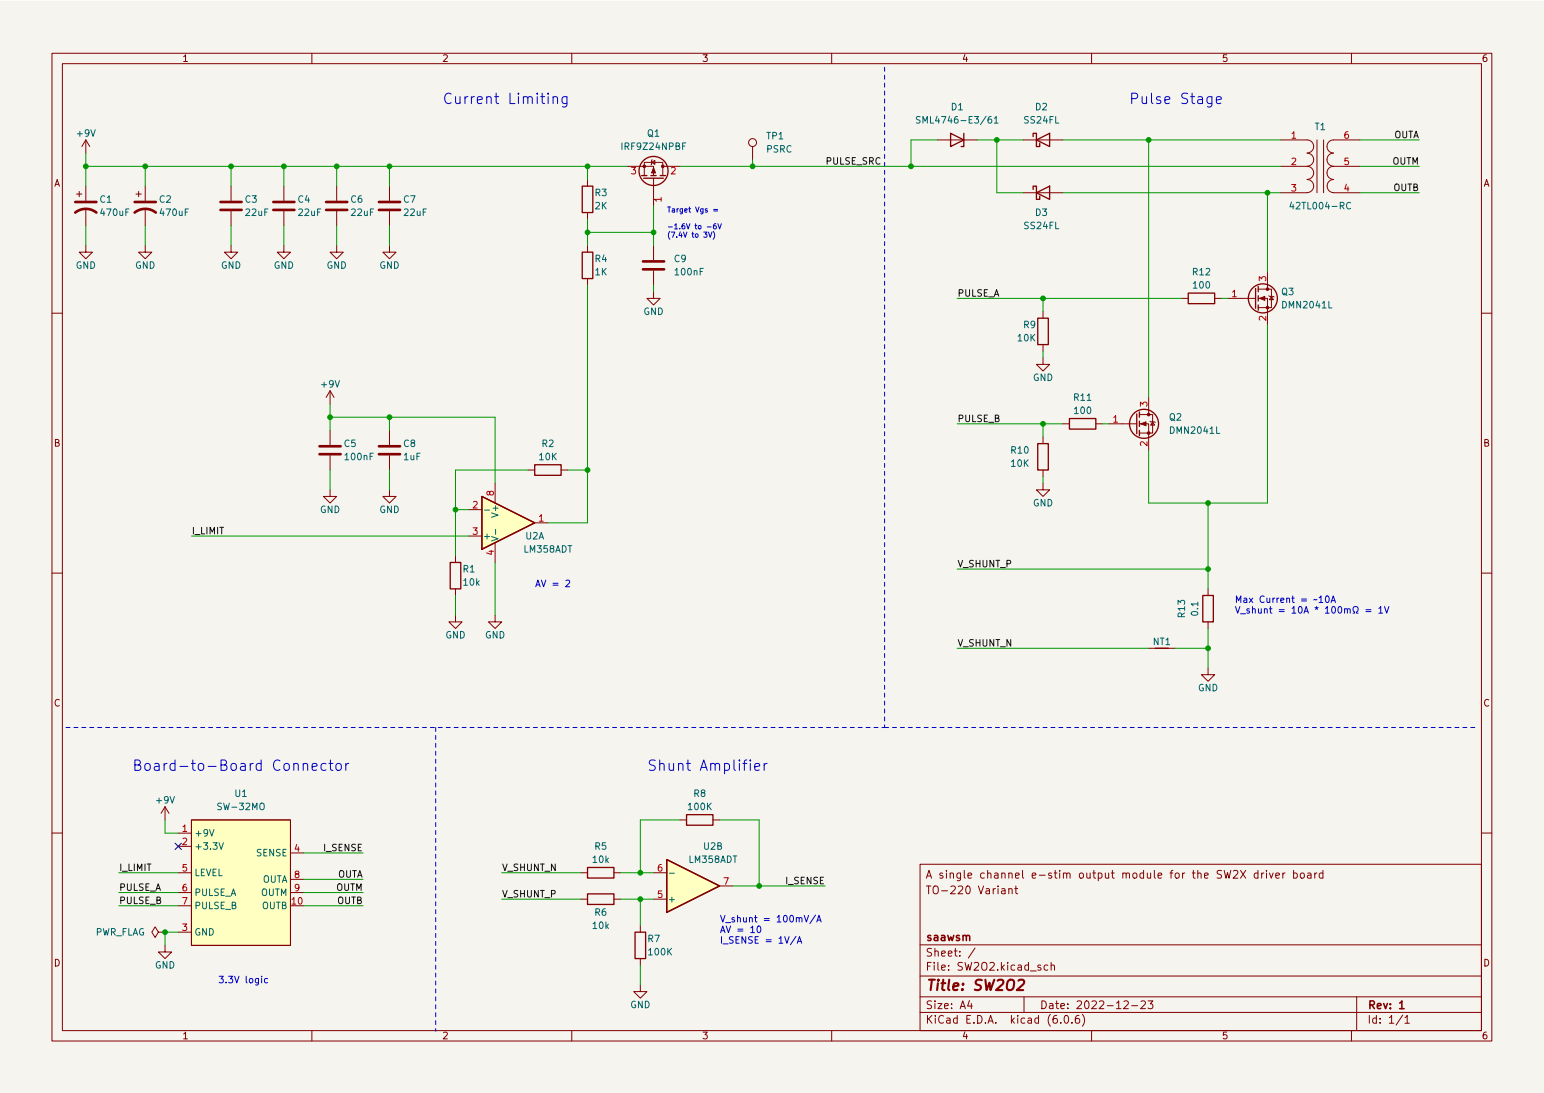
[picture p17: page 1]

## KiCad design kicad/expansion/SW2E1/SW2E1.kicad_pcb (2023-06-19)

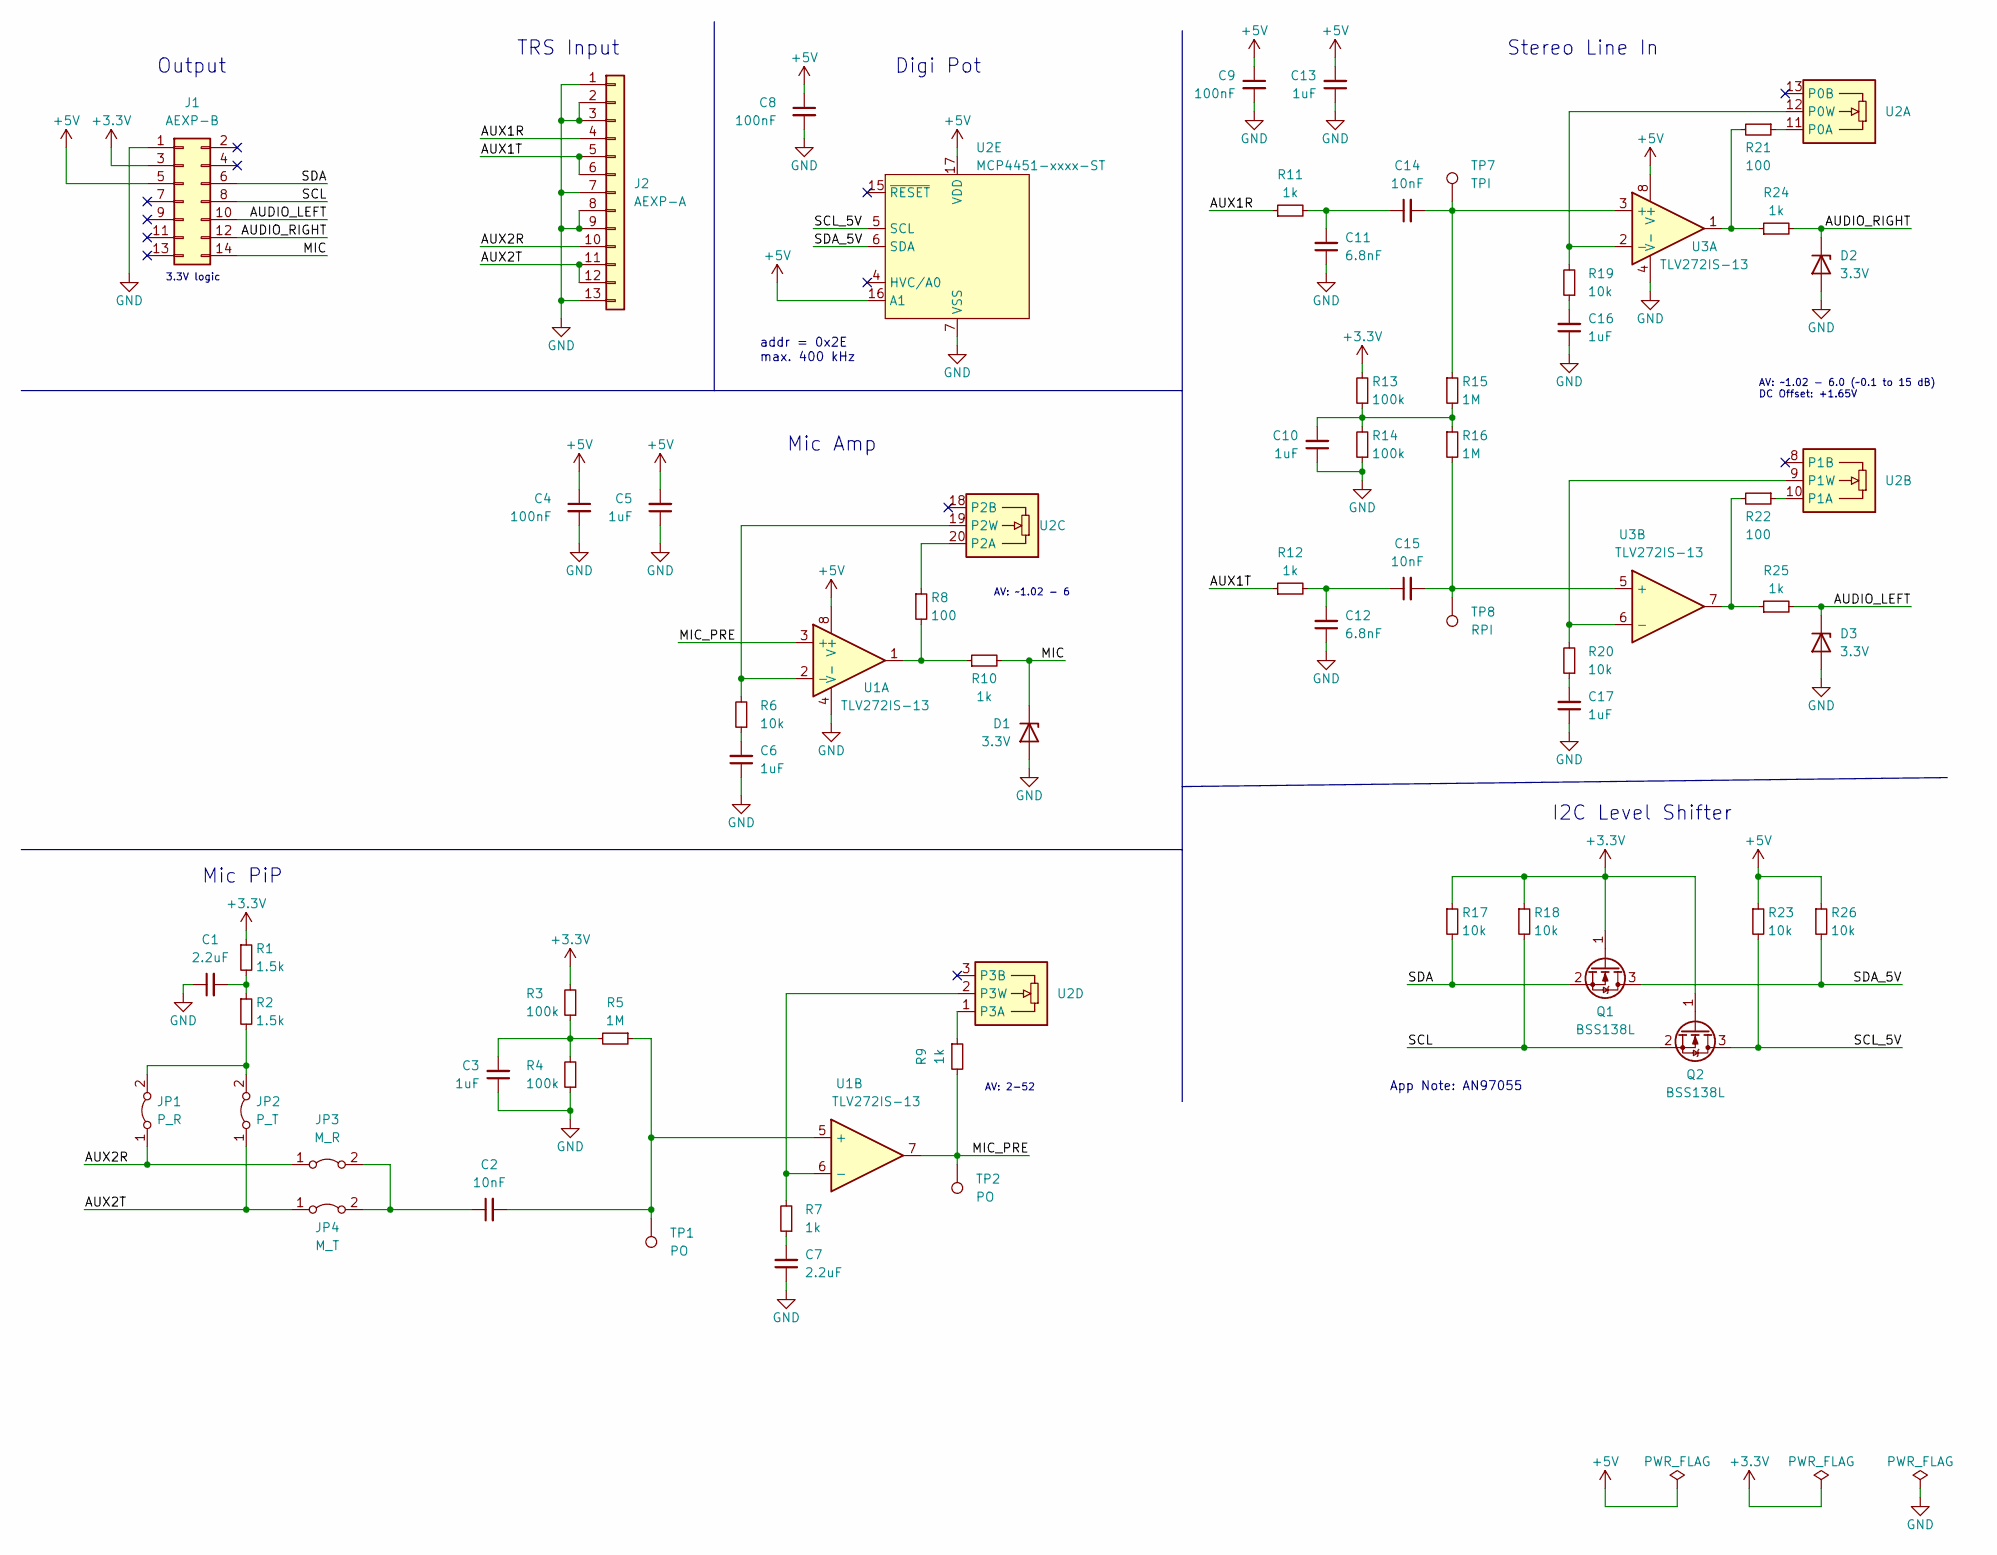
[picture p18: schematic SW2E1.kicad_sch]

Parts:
C1, C7: 2.2uF; C_0603_1608Metric
C2, C14, C15: 10nF; C_0603_1608Metric
C3, C5, C6, C10, C13, C16, C17: 1uF; C_0603_1608Metric
C4, C8, C9: 100nF; C_0603_1608Metric
C11, C12: 6.8nF; C_0603_1608Metric
D1, D2, D3: 3.3V; D_SOD-123F
J1: AEXP-B; PinHeader_2x07_P2.54mm_Vertical
J2: AEXP-A; PinHeader_1x13_P2.54mm_Vertical
JP1: P_R; PinHeader_1x02_P2.54mm_Vertical
JP2: P_T; PinHeader_1x02_P2.54mm_Vertical
JP3: M_R; PinHeader_1x02_P2.54mm_Vertical
JP4: M_T; PinHeader_1x02_P2.54mm_Vertical
Q1, Q2: BSS138L; SOT-23
R1, R2: 1.5k; R_0603_1608Metric
R3, R4, R13, R14: 100k; R_0603_1608Metric
R5, R15, R16: 1M; R_0603_1608Metric
R6, R17, R18, R19, R20, R23, R26: 10k; R_0603_1608Metric
R7, R9, R10, R11, R12, R24, R25: 1k; R_0603_1608Metric
R8, R21, R22: 100; R_0603_1608Metric
TP1, TP2: PO; TestPoint_Pad_D1.5mm
TP7: TPI; TestPoint_Pad_D1.5mm
TP8: RPI; TestPoint_Pad_D1.5mm
U1, U3: TLV272IS-13; SOIC-8_3.9x4.9mm_P1.27mm
U2: MCP4451-xxxx-ST; TSSOP-20_4.4x6.5mm_P0.65mm

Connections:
+3.3V: J1.3, Q1.1 (G), Q2.1 (G), R1.1, R3.2, R13.2, R17.1, R18.1
+5V: C4.1, C5.2, C8.1, C9.1, C13.2, J1.5, R23.1, R26.1, U1.8 (V+), U2.16 (A1), U2.17 (VDD), U3.8 (V+)
/AUDIO_LEFT: D3.1 (K), J1.10, R25.2
/AUDIO_RIGHT: D2.1 (K), J1.12, R24.2
/AUX1R: J2.4, R11.1
/AUX1T: J2.5, J2.6, R12.1
/AUX2R: J2.10, JP1.1 (A), JP3.1 (A)
/AUX2T: J2.11, J2.12, JP2.1 (A), JP4.1 (A)
/MIC: D1.1 (K), J1.14, R10.2
/MIC_PRE: R9.2, TP2.1, U1.3 (+), U1.7
/SCL: J1.8, Q2.2 (S), R18.2
/SCL_5V: Q2.3 (D), R23.2, U2.5 (SCL)
/SDA: J1.6, Q1.2 (S), R17.2
/SDA_5V: Q1.3 (D), R26.2, U2.6 (SDA)
GND: C1.1, C3.1, C4.2, C5.1, C6.1, C7.1, C8.2, C9.2, C10.1, C11.1, C12.1, C13.1, C16.1, C17.1, D1.2 (A), D2.2 (A), D3.2 (A), J1.1, J2.1, J2.2, J2.3, J2.7, J2.8, J2.9, J2.13, R4.1, R14.1, U1.4 (V-), U2.7 (VSS), U3.4 (V-)
unnamed: C1.2, R1.2, R2.1
unnamed: C2.1, JP3.2 (B), JP4.2 (B)
unnamed: C2.2, R5.1, TP1.1, U1.5 (+)
unnamed: C3.2, R3.1, R4.2, R5.2
unnamed: C6.2, R6.1
unnamed: C7.2, R7.1
unnamed: C10.2, R13.1, R14.2, R15.2, R16.1
unnamed: C11.2, C14.1, R11.2
unnamed: C12.2, C15.1, R12.2
unnamed: C14.2, R15.1, TP7.1, U3.3 (+)
unnamed: C15.2, R16.2, TP8.1, U3.5 (+)
unnamed: C16.2, R19.1
unnamed: C17.2, R20.1
unnamed: JP1.2 (B), JP2.2 (B), R2.2
unnamed: R6.2, U1.2 (-), U2.19 (P2W)
unnamed: R7.2, U1.6 (-), U2.2 (P3W)
unnamed: R8.1, U2.20 (P2A)
unnamed: R9.1, U2.1 (P3A)
unnamed: R8.2, R10.1, U1.1
unnamed: R19.2, U2.12 (P0W), U3.2 (-)
unnamed: R20.2, U2.9 (P1W), U3.6 (-)
unnamed: R21.1, U2.11 (P0A)
unnamed: R21.2, R24.1, U3.1
unnamed: R22.1, U2.10 (P1A)
unnamed: R22.2, R25.1, U3.7

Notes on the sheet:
I2C Level Shifter
App Note: AN97055
addr = 0x2E max. 400 kHz
TRS Input
Digi Pot
Mic PiP
Stereo Line In
Mic Amp
AV: ~1.02 - 6.0 (~0.1 to 15 dB) DC Offset: +1.65V
Output
AV: ~1.02 - 6
3.3V logic
AV: 2-52

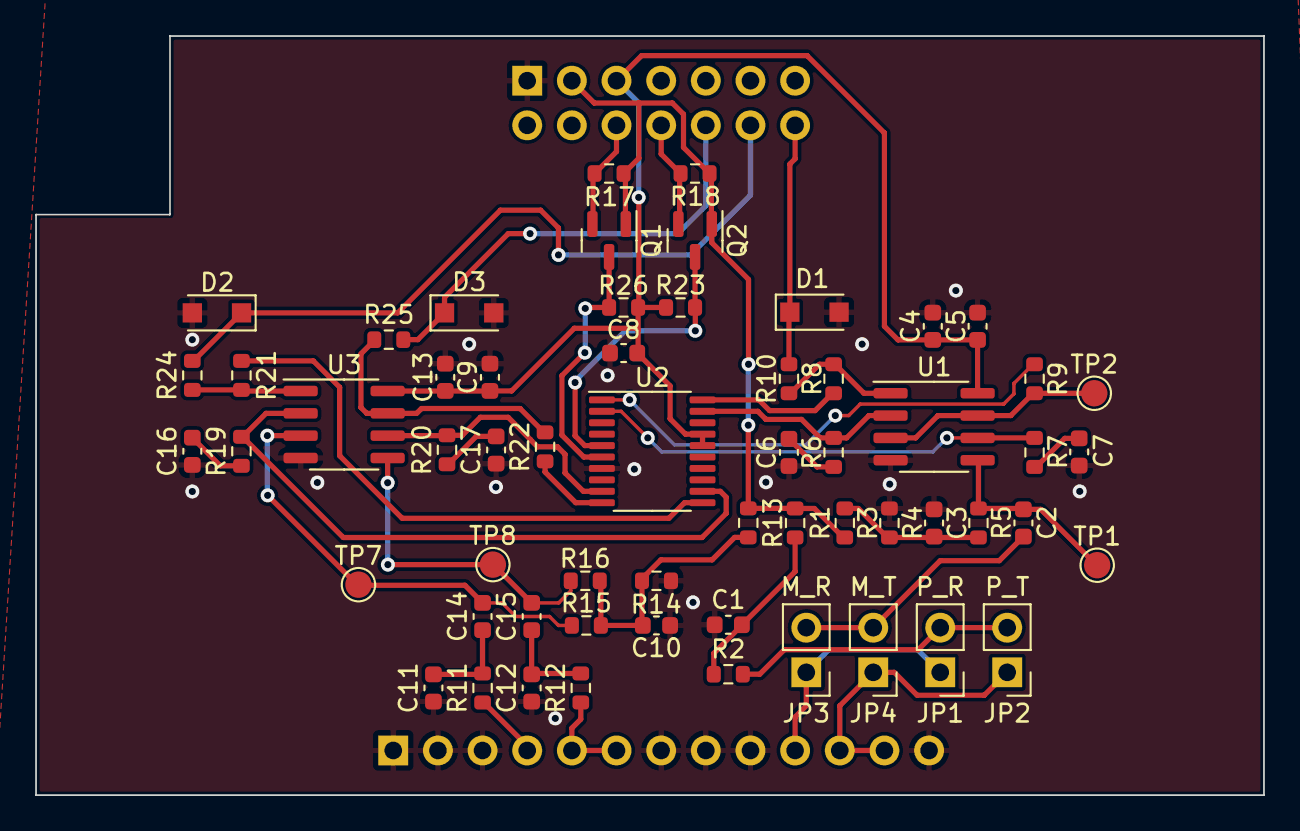
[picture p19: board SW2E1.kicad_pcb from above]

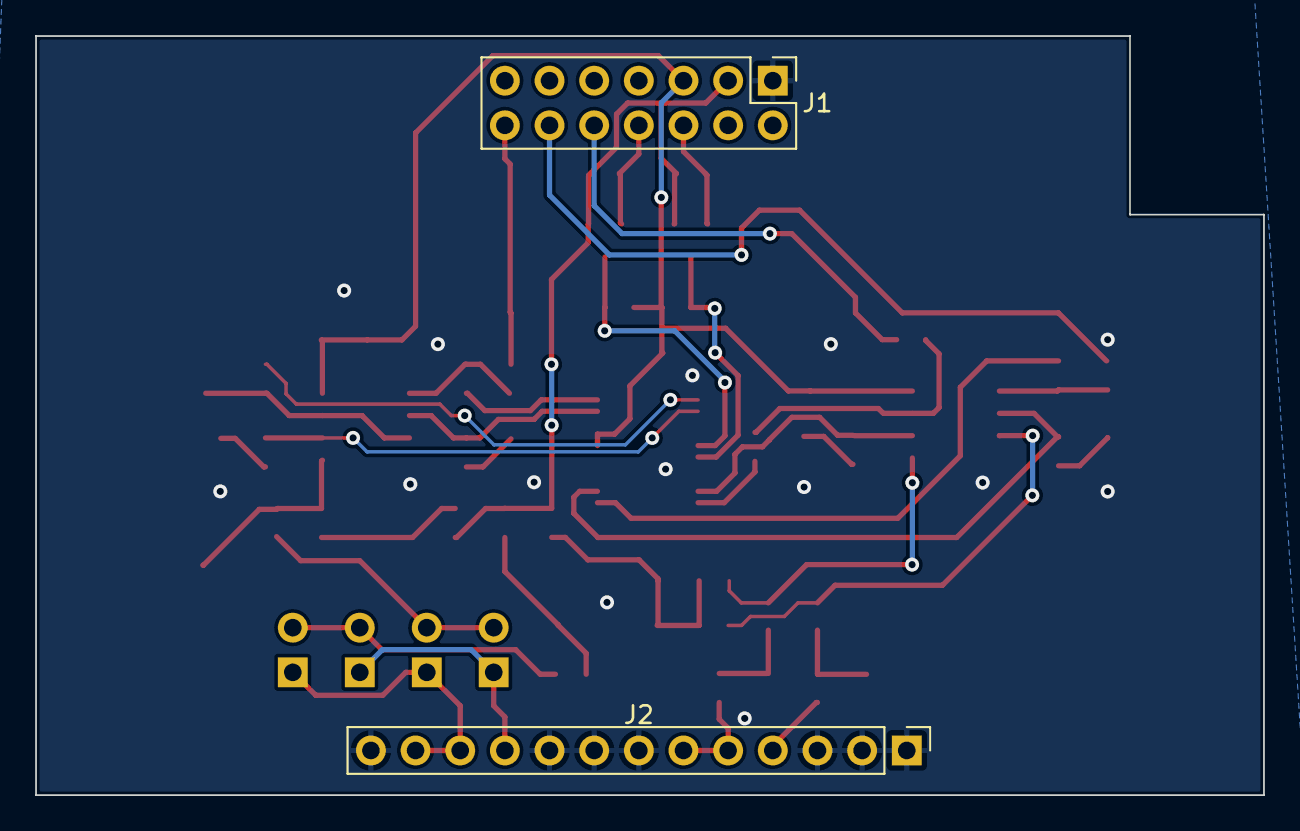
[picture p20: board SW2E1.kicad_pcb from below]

Board: 2 copper layers, 69.9 x 43.2 mm, 61 parts (2 on the bottom side), 40 nets.

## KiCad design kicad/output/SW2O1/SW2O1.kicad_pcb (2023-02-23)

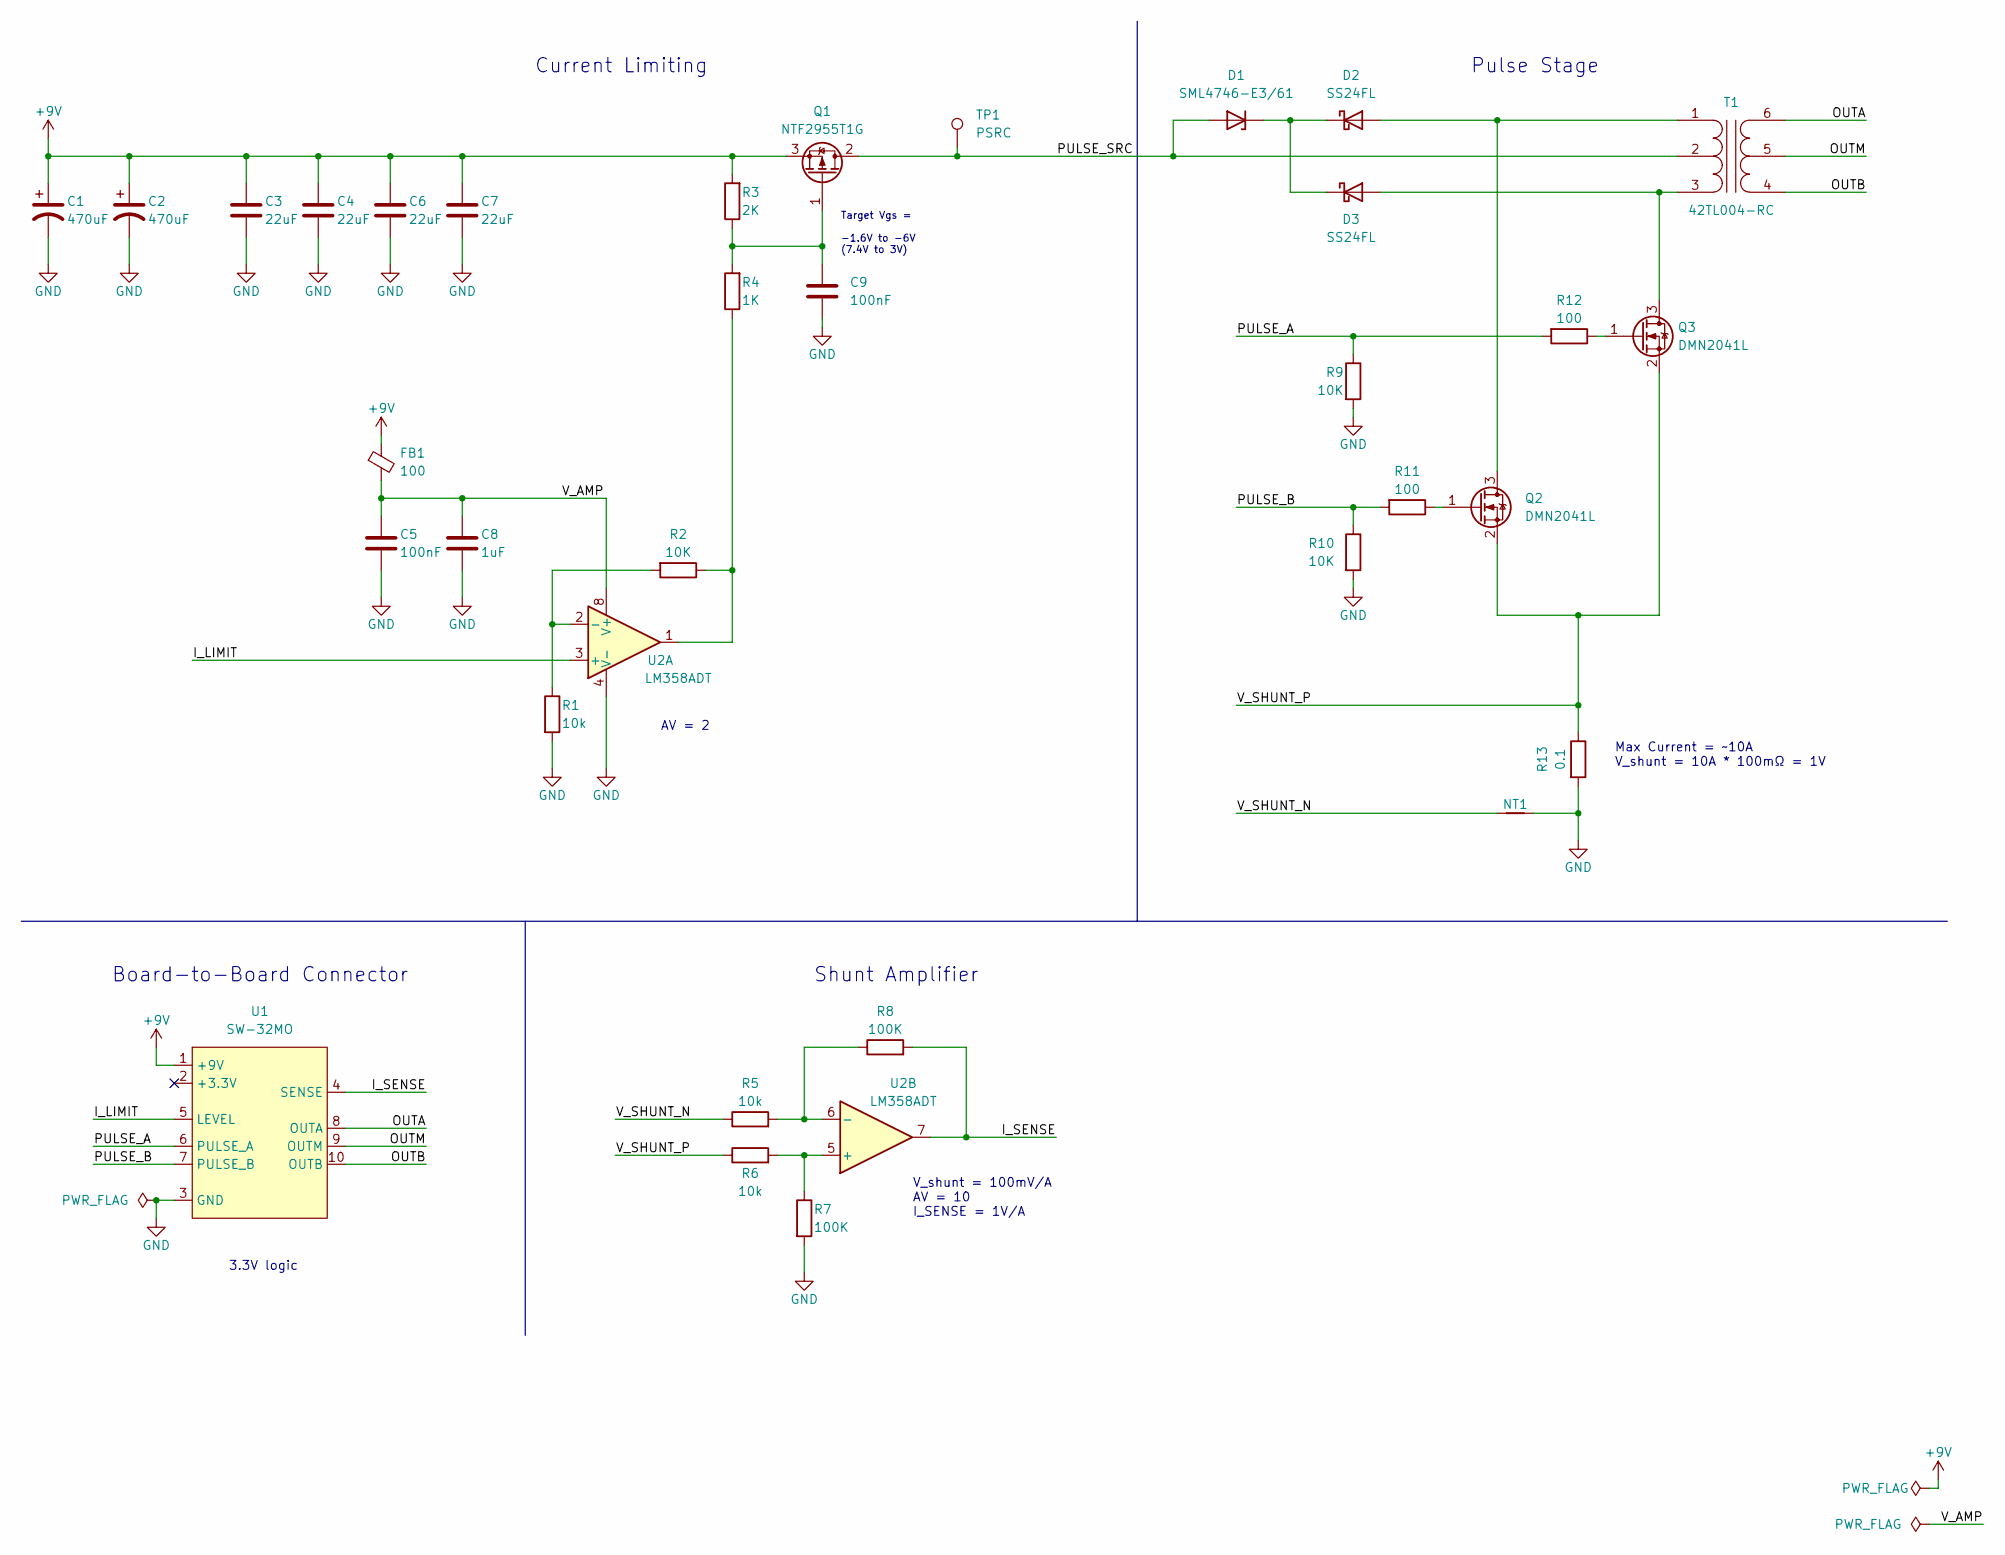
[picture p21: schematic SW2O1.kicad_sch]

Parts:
C1, C2: 470uF; CP_Radial_D8.0mm_P3.50mm; MPN 477CKE016M
C3, C4, C6, C7: 22uF; C_1210_3225Metric; MPN CL32A226KAJNNNE
C5, C9: 100nF; C_0603_1608Metric; MPN CL10B104KB8NNWC
C8: 1uF; C_0603_1608Metric; MPN CL10B105KA8NFNC
D1: SML4746-E3/61; D_SMA; MPN SML4746-E3/61
D2: SS24FL; D_SOD-123F; MPN SS24FL; LCSC C894433
D3: SS24FL; D_SOD-123F; MPN SS24FL; MOUSER 512-SS24FL
FB1: 100; R_0603_1608Metric; MPN BLM18KG101TN1D
NT1: 0.5 mm; NetTie-2_SMD_Pad0.5mm
Q1: NTF2955T1G; SOT-223-3_TabPin2; MPN NTF2955T1G
Q2, Q3: DMN2041L; SOT-23; MPN DMN2041L
R1, R5, R6: 10k; R_0603_1608Metric; MPN RC0603FR-0710KL
R2, R9, R10: 10K; R_0603_1608Metric; MPN RC0603FR-0710KL
R3: 2K; R_0603_1608Metric; MPN RC0603FR-072KL
R4: 1K; R_0603_1608Metric; MPN RC0603FR-071KL
R7, R8: 100K; R_0603_1608Metric; MPN RC0603FR-07100KL
R11, R12: 100; R_0603_1608Metric; MPN RC0603FR-07100RL
R13: 0.1; R_1206_3216Metric; MPN ERJ-8BWFR100V
T1: 42TL004-RC; 42TL; MPN 42TL004-RC
TP1: PSRC; TestPoint_Pad_D1.5mm
U1: SW-32MO; SW32-MO_Header
U2: LM358ADT; SOIC-8_3.9x4.9mm_P1.27mm; MPN LM358ADT

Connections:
+9V: C1.1, C2.1, C3.1, C4.1, C6.1, C7.1, FB1.1, Q1.3 (S), R3.2, U1.1 (+9V)
/I_LIMIT: U1.5 (LEVEL), U2.3 (+)
/I_SENSE: R8.2, U1.4 (SENSE), U2.7
/OUTA: T1.6 (S2), U1.8 (OUTA)
/OUTB: T1.4 (S1), U1.10 (OUTB)
/OUTM: T1.5 (SM), U1.9 (OUTM)
/PULSE_A: R9.1, R12.2, U1.6 (PULSE_A)
/PULSE_B: R10.1, R11.2, U1.7 (PULSE_B)
/PULSE_SRC: D1.2 (A), Q1.2 (D), T1.2 (PM), TP1.1
/V_AMP: C5.1, C8.1, FB1.2, U2.8 (V+)
/V_SHUNT_N: NT1.1, R5.1
/V_SHUNT_P: Q2.2 (S), Q3.2 (S), R6.1, R13.1
GND: C1.2, C2.2, C3.2, C4.2, C5.2, C6.2, C7.2, C8.2, C9.1, NT1.2, R1.2, R7.2, R9.2, R10.2, R13.2, U1.3 (GND), U2.4 (V-)
unnamed: C9.2, Q1.1 (G), R3.1, R4.2
unnamed: D1.1 (K), D2.1 (K), D3.1 (K)
unnamed: D2.2 (A), Q2.3 (D), T1.1 (PR1)
unnamed: D3.2 (A), Q3.3 (D), T1.3 (PR2)
unnamed: Q2.1 (G), R11.1
unnamed: Q3.1 (G), R12.1
unnamed: R1.1, R2.2, U2.2 (-)
unnamed: R2.1, R4.1, U2.1
unnamed: R5.2, R8.1, U2.6 (-)
unnamed: R6.2, R7.1, U2.5 (+)

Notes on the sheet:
Max Current = ~10A V_shunt = 10A * 100mΩ = 1V
Board-to-Board Connector
V_shunt = 100mV/A AV = 10 I_SENSE = 1V/A
AV = 2
Shunt Amplifier
Pulse Stage
Target Vgs = -1.6V to -6V (7.4V to 3V)
Current Limiting
3.3V logic

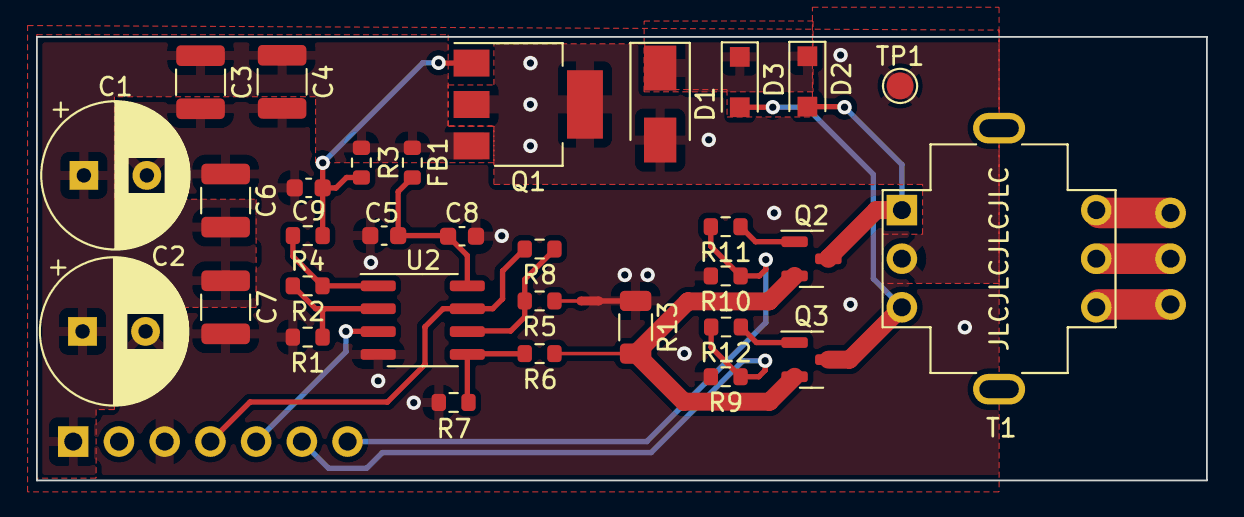
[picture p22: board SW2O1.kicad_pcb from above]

Board: 2 copper layers, 65.0 x 24.6 mm, 34 parts (0 on the bottom side), 23 nets.

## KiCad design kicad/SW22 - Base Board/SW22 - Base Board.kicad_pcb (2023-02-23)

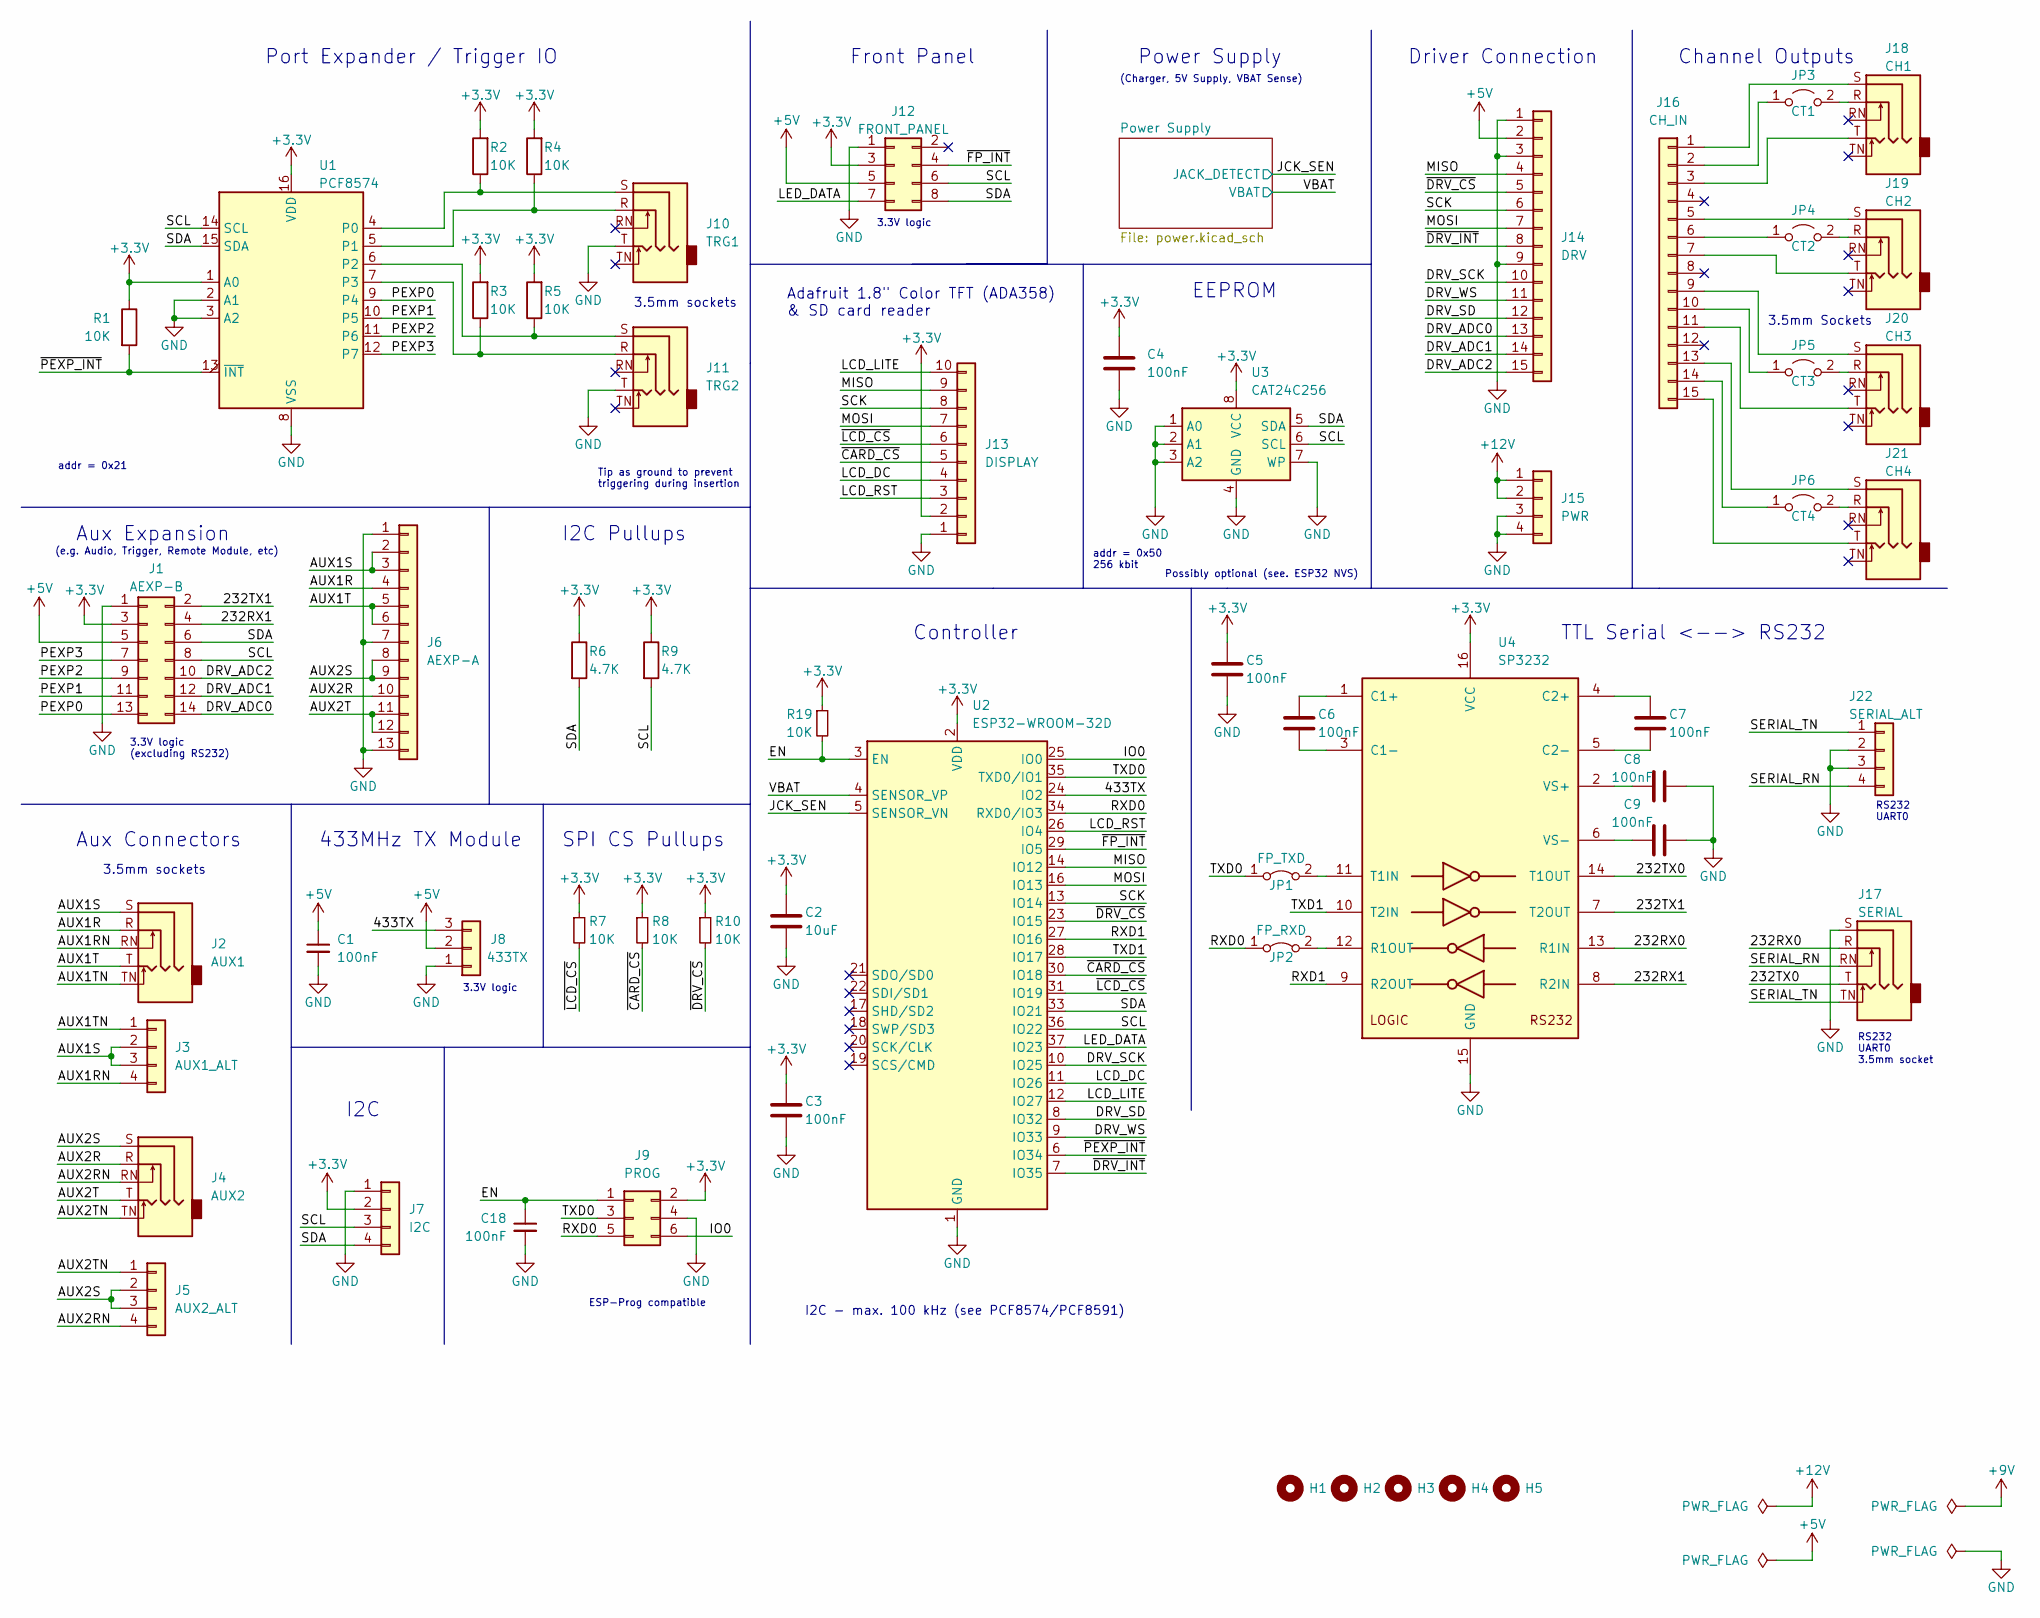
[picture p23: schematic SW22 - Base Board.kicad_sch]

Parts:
C1, C3, C4, C5, C6, C7, C8, C9, C18: 100nF; C_0603_1608Metric; MPN CL10B104KB8NNNC; LCSC C1591
C2: 10uF; C_0603_1608Metric; MPN CL10A106MA8NRNC; LCSC C96446
H1, H2, H3, H4, H5: MountingHole; MountingHole_2.2mm_M2
J1: AEXP-B; PinSocket_2x07_P2.54mm_Vertical
J2: AUX1; STX-3100-5N; MPN STX-3100-5N; MOUSER 806-STX-3100-5N
J3: AUX1_ALT; PinHeader_1x04_P2.54mm_Vertical
J4: AUX2; STX-3100-5N; MPN STX-3100-5N; MOUSER 806-STX-3100-5N
J5: AUX2_ALT; PinHeader_1x04_P2.54mm_Vertical
J6: AEXP-A; PinSocket_1x13_P2.54mm_Vertical
J7: I2C; PinHeader_1x04_P2.54mm_Vertical
J8: 433TX; PinSocket_1x03_P2.54mm_Vertical
J9: PROG; IDC-Header_2x03_P2.54mm_Vertical
J10: TRG1; STX-3100-5N; MPN STX-3100-5N; MOUSER 806-STX-3100-5N
J11: TRG2; STX-3100-5N; MPN STX-3100-5N; MOUSER 806-STX-3100-5N
J12: FRONT_PANEL; IDC-Header_2x04_P2.54mm_Vertical
J13: DISPLAY; PinHeader_1x10_P2.54mm_Vertical
J14: DRV; PinSocket_1x15_P2.54mm_Vertical
J15: PWR; PinSocket_1x04_P2.54mm_Vertical
J16: CH_IN; PinSocket_1x15_P2.54mm_Vertical
J17: SERIAL; STX-3100-5N; MPN STX-3100-5N; MOUSER 806-STX-3100-5N
J18: CH1; STX-3100-5N; MPN STX-3100-5N; MOUSER 806-STX-3100-5N
J19: CH2; STX-3100-5N; MPN STX-3100-5N; MOUSER 806-STX-3100-5N
J20: CH3; STX-3100-5N; MPN STX-3100-5N; MOUSER 806-STX-3100-5N
J21: CH4; STX-3100-5N; MPN STX-3100-5N; MOUSER 806-STX-3100-5N
J22: SERIAL_ALT; PinHeader_1x04_P2.54mm_Vertical
JP1: FP_TXD; PinHeader_1x02_P2.54mm_Vertical
JP2: FP_RXD; PinHeader_1x02_P2.54mm_Vertical
JP3: CT1; PinHeader_1x02_P2.54mm_Vertical
JP4: CT2; PinHeader_1x02_P2.54mm_Vertical
JP5: CT3; PinHeader_1x02_P2.54mm_Vertical
JP6: CT4; PinHeader_1x02_P2.54mm_Vertical
R1, R2, R3, R4, R5, R7, R8, R10, R19: 10K; R_0603_1608Metric; MPN RC0603FR-0710KL; MOUSER 603-RC0603FR-0710KL
R6, R9: 4.7K; R_0603_1608Metric; MPN RC0603FR-074K7L; MOUSER 603-RC0603FR-074K7L
U1: PCF8574; SOIC-16W_7.5x10.3mm_P1.27mm; MPN PCF8574T/3,512; LCSC C1522621
U2: ESP32-WROOM-32D; ESP32-WROOM-32; MPN ESP32-WROOM-32D-N16
U3: CAT24C256; SOIC-8_3.9x4.9mm_P1.27mm; MPN CAT24C256WI-GT3; LCSC C79987
U4: SP3232; SOIC-16_3.9x9.9mm_P1.27mm; MPN SP3232EEN-L/TR; LCSC C9378

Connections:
+3.3V: C2.1, C3.2, C4.2, C5.2, J1.3, J7.2, J9.2, J12.3, J13.2, R1.1, R2.2, R3.2, R4.2, R5.2, R6.1, R7.1, R8.1, R9.1, R10.1, R19.1, U1.1 (A0), U1.16 (VDD), U2.2 (VDD), U3.8 (VCC), U4.16 (VCC); also elsewhere on the board
+5V: C1.1, J1.5, J8.2, J12.5, J14.2; also elsewhere on the board
+12V: J15.1, J15.2; also elsewhere on the board
/232RX0: J17.R, U4.13 (R1IN)
/232RX1: J1.4, U4.8 (R2IN)
/232TX0: J17.T, U4.14 (T1OUT)
/232TX1: J1.2, U4.7 (T2OUT)
/433TX: J8.3, U2.24 (IO2)
/AUX1R: J2.R, J6.4
/AUX1RN: J2.RN, J3.4
/AUX1S: J2.S, J3.2, J3.3, J6.2, J6.3
/AUX1T: J2.T, J6.5, J6.6
/AUX1TN: J2.TN, J3.1
/AUX2R: J4.R, J6.10
/AUX2RN: J4.RN, J5.4
/AUX2S: J4.S, J5.2, J5.3, J6.8, J6.9
/AUX2T: J4.T, J6.11, J6.12
/AUX2TN: J4.TN, J5.1
/DRV_ADC0: J1.14, J14.13
/DRV_ADC1: J1.12, J14.14
/DRV_ADC2: J1.10, J14.15
/DRV_SCK: J14.10, U2.10 (IO25)
/DRV_SD: J14.12, U2.8 (IO32)
/DRV_WS: J14.11, U2.9 (IO33)
/EN: C18.1, J9.1, R19.2, U2.3 (EN)
/IO0: J9.6, U2.25 (IO0)
/JCK_SEN: U2.5 (SENSOR_VN); also elsewhere on the board
/LCD_DC: J13.4, U2.11 (IO26)
/LCD_LITE: J13.10, U2.12 (IO27)
/LCD_RST: J13.3, U2.26 (IO4)
/LED_DATA: J12.7, U2.37 (IO23)
/MISO: J13.9, J14.4, U2.14 (IO12)
/MOSI: J13.7, J14.7, U2.16 (IO13)
/PEXP0: J1.13, U1.9 (P4)
/PEXP1: J1.11, U1.10 (P5)
/PEXP2: J1.9, U1.11 (P6)
/PEXP3: J1.7, U1.12 (P7)
/RXD0: J9.5, JP2.1 (A), U2.34 (RXD0/IO3); also elsewhere on the board
/RXD1: U2.27 (IO16), U4.9 (R2OUT)
/SCK: J13.8, J14.6, U2.13 (IO14)
/SCL: J1.8, J7.3, J12.6, R9.2, U1.14 (SCL), U2.36 (IO22), U3.6 (SCL)
/SDA: J1.6, J7.4, J12.8, R6.2, U1.15 (SDA), U2.33 (IO21), U3.5 (SDA)
/SERIAL_RN: J17.RN, J22.4
/SERIAL_TN: J17.TN, J22.1
/TXD0: J9.3, JP1.1 (A), U2.35 (TXD0/IO1)
/TXD1: U2.28 (IO17), U4.10 (T2IN)
/VBAT: U2.4 (SENSOR_VP); also elsewhere on the board
/~CARD_CS: J13.5, R8.2, U2.30 (IO18)
/~DRV_CS: J14.5, R10.2, U2.23 (IO15)
/~DRV_INT: J14.8, U2.7 (IO35)
/~FP_INT: J12.4, U2.29 (IO5)
/~LCD_CS: J13.6, R7.2, U2.31 (IO19)
/~PEXP_INT: R1.2, U1.13 (~INT), U2.6 (IO34)
GND: C1.2, C2.2, C3.1, C4.1, C5.1, C8.1, C9.1, C18.2, J1.1, J6.1, J6.7, J6.13, J7.1, J8.1, J9.4, J10.T, J11.T, J12.1, J13.1, J14.1, J14.3, J14.9, J15.3, J15.4, J17.S, J22.2, J22.3, U1.2 (A1), U1.3 (A2), U1.8 (VSS), U2.1 (GND), U2.15 (GND), U2.38 (GND), U2.39 (GND), U3.1 (A0), U3.2 (A1), U3.3 (A2), U3.4 (GND), U3.7 (WP), U4.15 (GND); also elsewhere on the board
unnamed: C6.1, U4.3 (C1-)
unnamed: C6.2, U4.1 (C1+)
unnamed: C7.1, U4.5 (C2-)
unnamed: C7.2, U4.4 (C2+)
unnamed: C8.2, U4.2 (VS+)
unnamed: C9.2, U4.6 (VS-)
unnamed: J10.R, R4.1, U1.5 (P1)
unnamed: J10.S, R2.1, U1.4 (P0)
unnamed: J11.R, R3.1, U1.7 (P3)
unnamed: J11.S, R5.1, U1.6 (P2)
unnamed: J16.1, J18.S
unnamed: J16.2, JP3.1 (A)
unnamed: J16.3, J18.T
unnamed: J16.5, J19.S
unnamed: J16.6, JP4.1 (A)
unnamed: J16.7, J19.T
unnamed: J16.9, J20.S
unnamed: J16.10, JP5.1 (A)
unnamed: J16.11, J20.T
unnamed: J16.13, J21.S
unnamed: J16.14, JP6.1 (A)
unnamed: J16.15, J21.T
unnamed: J18.R, JP3.2 (B)
unnamed: J19.R, JP4.2 (B)
unnamed: J20.R, JP5.2 (B)
unnamed: J21.R, JP6.2 (B)
unnamed: JP1.2 (B), U4.11 (T1IN)
unnamed 89: JP2.2 (B), U4.12 (R1OUT); also elsewhere on the board

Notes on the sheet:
EEPROM
addr = 0x21
Adafruit 1.8" Color TFT (ADA358) & SD card reader
433MHz TX Module
I2C
(e.g. Audio, Trigger, Remote Module, etc)
Aux Connectors
3.3V logic (excluding RS232)
Tip as ground to prevent triggering during insertion
3.5mm sockets
3.3V logic
Possibly optional (see. ESP32 NVS)
Port Expander / Trigger IO
addr = 0x50 256 kbit
I2C Pullups
(Charger, 5V Supply, VBAT Sense)
ESP-Prog compatible
RS232 UART0 3.5mm socket
3.5mm Sockets
Power Supply
Driver Connection
SPI CS Pullups
I2C - max. 100 kHz (see PCF8574/PCF8591)
TTL Serial <--> RS232
Channel Outputs
Aux Expansion
Controller
Front Panel
RS232 UART0

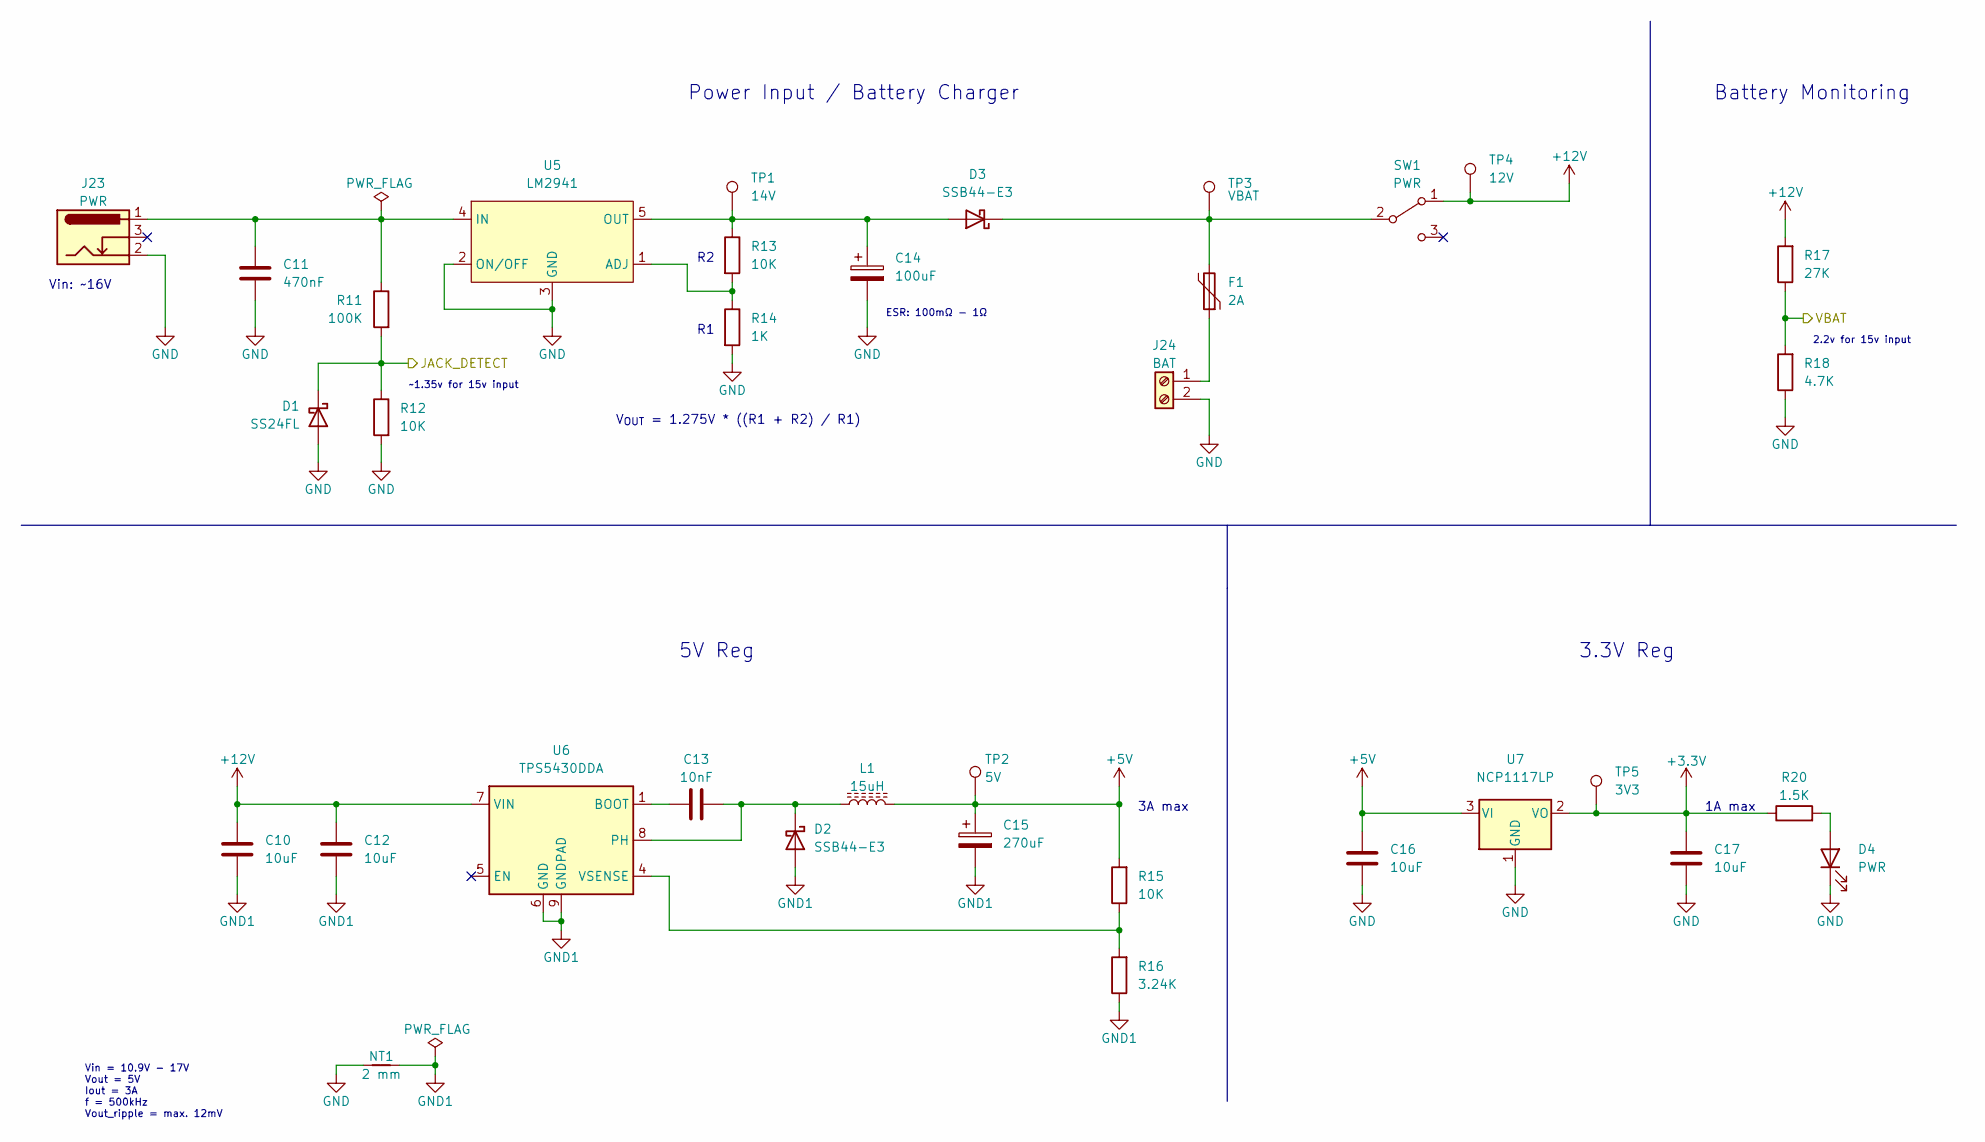
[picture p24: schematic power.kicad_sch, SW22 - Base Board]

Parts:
C10, C12: 10uF; C_1210_3225Metric; MPN CL32A106KBJNNNE; LCSC C380537
C11: 470nF; C_0603_1608Metric; MPN CL10A474KB8NNNC; LCSC C170149
C13: 10nF; C_0603_1608Metric; MPN CL10B103KB8NNNC; LCSC C1589
C14: 100uF; CP_Radial_D6.3mm_P2.50mm; MPN EEU-FM1E101; LCSC C1579509
C15: 270uF; CP_Elec_8x6.9; MPN 16SVPF270M; LCSC C136278
C16, C17: 10uF; C_0603_1608Metric; MPN CL10A106MA8NRNC; LCSC C96446
D1: SS24FL; D_SOD-123F; MPN SS24FL; LCSC C894433
D2: SSB44-E3; D_SMB; MPN SSB44-E3/52T; MOUSER 625-SSB44-E3
D3: SSB44-E3; D_SMB; MPN SSB44-E3/52T; LCSC C466999
D4: PWR; LED_0603_1608Metric; MPN 150060VS75000; MOUSER 710-150060VS75000
F1: 2A; Fuse_Littelfuse-LVR200; MPN LVR200S-240; LCSC C1562345
J23: PWR; BarrelJack_CUI_PJ-102AH_Horizontal; MPN PJ-102AH; MOUSER 490-PJ-102AH
J24: BAT; JST_XH_B2B-XH-A_1x02_P2.50mm_Vertical
L1: 15uH; L_Bourns_SRR1260; MPN SRR1260-150M; MOUSER 652-SRR1260-150M
NT1: 2 mm; NetTie-2_SMD_Pad2.0mm
R11: 100K; R_0603_1608Metric; MPN RC0603FR-07100KL; MOUSER 603-RC0603FR-07100KL
R12, R13, R15: 10K; R_0603_1608Metric; MPN RC0603FR-0710KL; MOUSER 603-RC0603FR-0710KL
R14: 1K; R_0603_1608Metric; MPN RC0603FR-071KL; MOUSER 603-RC0603FR-071KL
R16: 3.24K; R_0603_1608Metric; MPN RC0603FR-073K24L; LCSC C273779
R17: 27K; R_0603_1608Metric; MPN RC0603FR-0727KL; MOUSER 603-RC0603FR-0727KL
R18: 4.7K; R_0603_1608Metric; MPN RC0603FR-074K7L; MOUSER 603-RC0603FR-074K7L
R20: 1.5K; R_0603_1608Metric; MPN RC0603FR-071K5L; MOUSER 603-RC0603FR-071K5L
SW1: PWR; 500SSP1S2M6QEA; MPN 500SSP1S2M6QEA; MOUSER 612-500-A261
TP1: 14V; TestPoint_Pad_D1.5mm
TP2: 5V; TestPoint_Pad_D1.5mm
TP3: VBAT; TestPoint_Pad_D1.5mm
TP4: 12V; TestPoint_Pad_D1.5mm
TP5: 3V3; TestPoint_Pad_D1.5mm
U5: LM2941; TO-263-5_TabPin3; MPN LM2941CSX/NOPB; LCSC C512759
U6: TPS5430DDA; TI_SO-PowerPAD-8_ThermalVias; MPN TPS5430DDAR; LCSC C9864
U7: NCP1117LP; SOT-223-3_TabPin2; MPN NCP1117LPST33T3G; LCSC C146799

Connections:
+3.3V: C17.1, R20.1, TP5.1, U7.2 (VO); also elsewhere on the board
+5V: C15.1, C16.1, L1.2, R15.2, TP2.1, U7.3 (VI); also elsewhere on the board
+12V: C10.2, C12.2, R17.2, SW1.1 (A), TP4.1, U6.7 (VIN); also elsewhere on the board
/JCK_SEN: D1.1 (K), R11.2, R12.1; also elsewhere on the board
/VBAT: R17.1, R18.2; also elsewhere on the board
GND: C11.2, C14.2, C16.2, C17.2, D1.2 (A), D4.1 (K), J23.2, J24.2, NT1.2, R12.2, R14.2, R18.1, U5.2 (ON/OFF), U5.3 (GND), U7.1 (GND); also elsewhere on the board
GND1: C10.1, C12.1, C15.2, D2.2 (A), NT1.1, R16.1, U6.6 (GND), U6.9 (GNDPAD)
unnamed: C11.1, J23.1, R11.1, U5.4 (IN)
unnamed: C13.1, U6.1 (BOOT)
unnamed: C13.2, D2.1 (K), L1.1, U6.8 (PH)
unnamed: C14.1, D3.2 (A), R13.1, TP1.1, U5.5 (OUT)
unnamed: D3.1 (K), F1.2, SW1.2 (B), TP3.1
unnamed: D4.2 (A), R20.2
unnamed: F1.1, J24.1
unnamed: R13.2, R14.1, U5.1 (ADJ)
unnamed: R15.1, R16.2, U6.4 (VSENSE)

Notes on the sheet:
Vin = 10.9V - 17V Vout = 5V Iout = 3A f = 500kHz Vout_ripple = max. 12mV
V_{OUT} = 1.275V * ((R1 + R2) / R1)
ESR: 100mΩ - 1Ω
Battery Monitoring
2.2v for 15v input
~1.35v for 15v input
Vin: ~16V
3.3V Reg
Power Input / Battery Charger
5V Reg
3A max
1A max

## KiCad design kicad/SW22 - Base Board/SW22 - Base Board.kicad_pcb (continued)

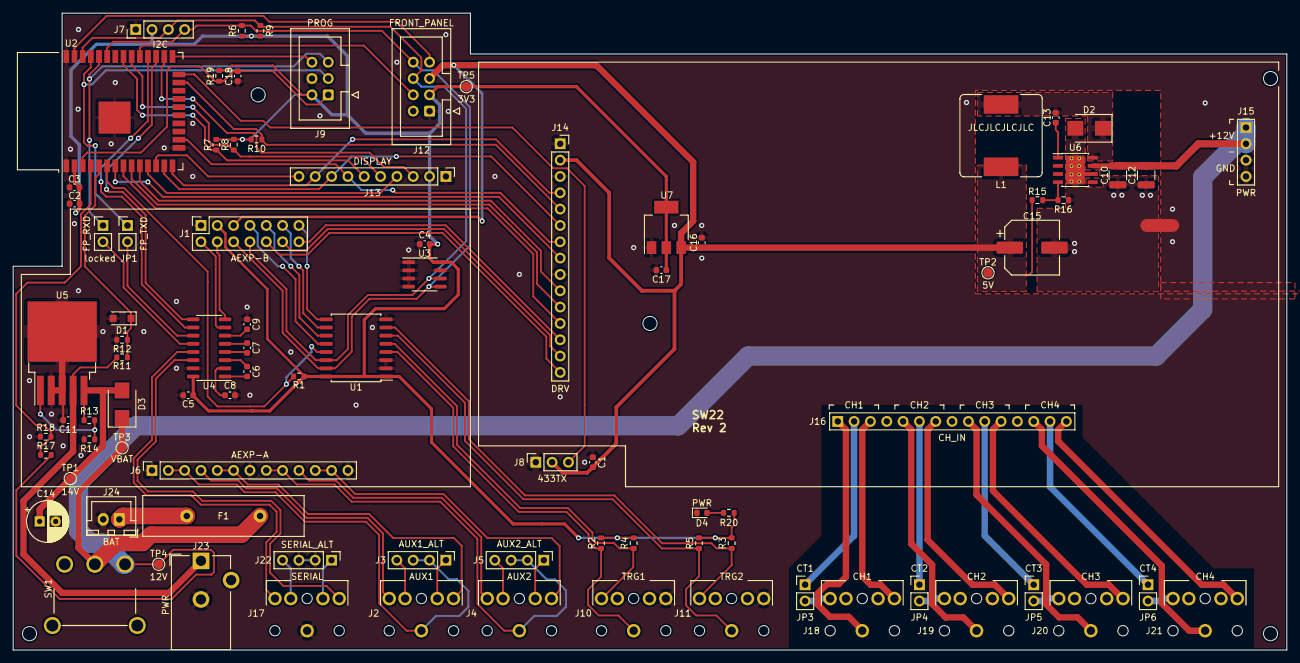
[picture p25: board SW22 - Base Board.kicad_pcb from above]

Board: 2 copper layers, 198.1 x 99.1 mm, 93 parts (0 on the bottom side), 92 nets.

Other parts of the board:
locked: FP_RXD; PinHeader_1x02_P2.54mm_Vertical

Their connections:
/RXD0: locked.1 (A); also elsewhere on the board
unnamed 89: locked.2 (B); also elsewhere on the board

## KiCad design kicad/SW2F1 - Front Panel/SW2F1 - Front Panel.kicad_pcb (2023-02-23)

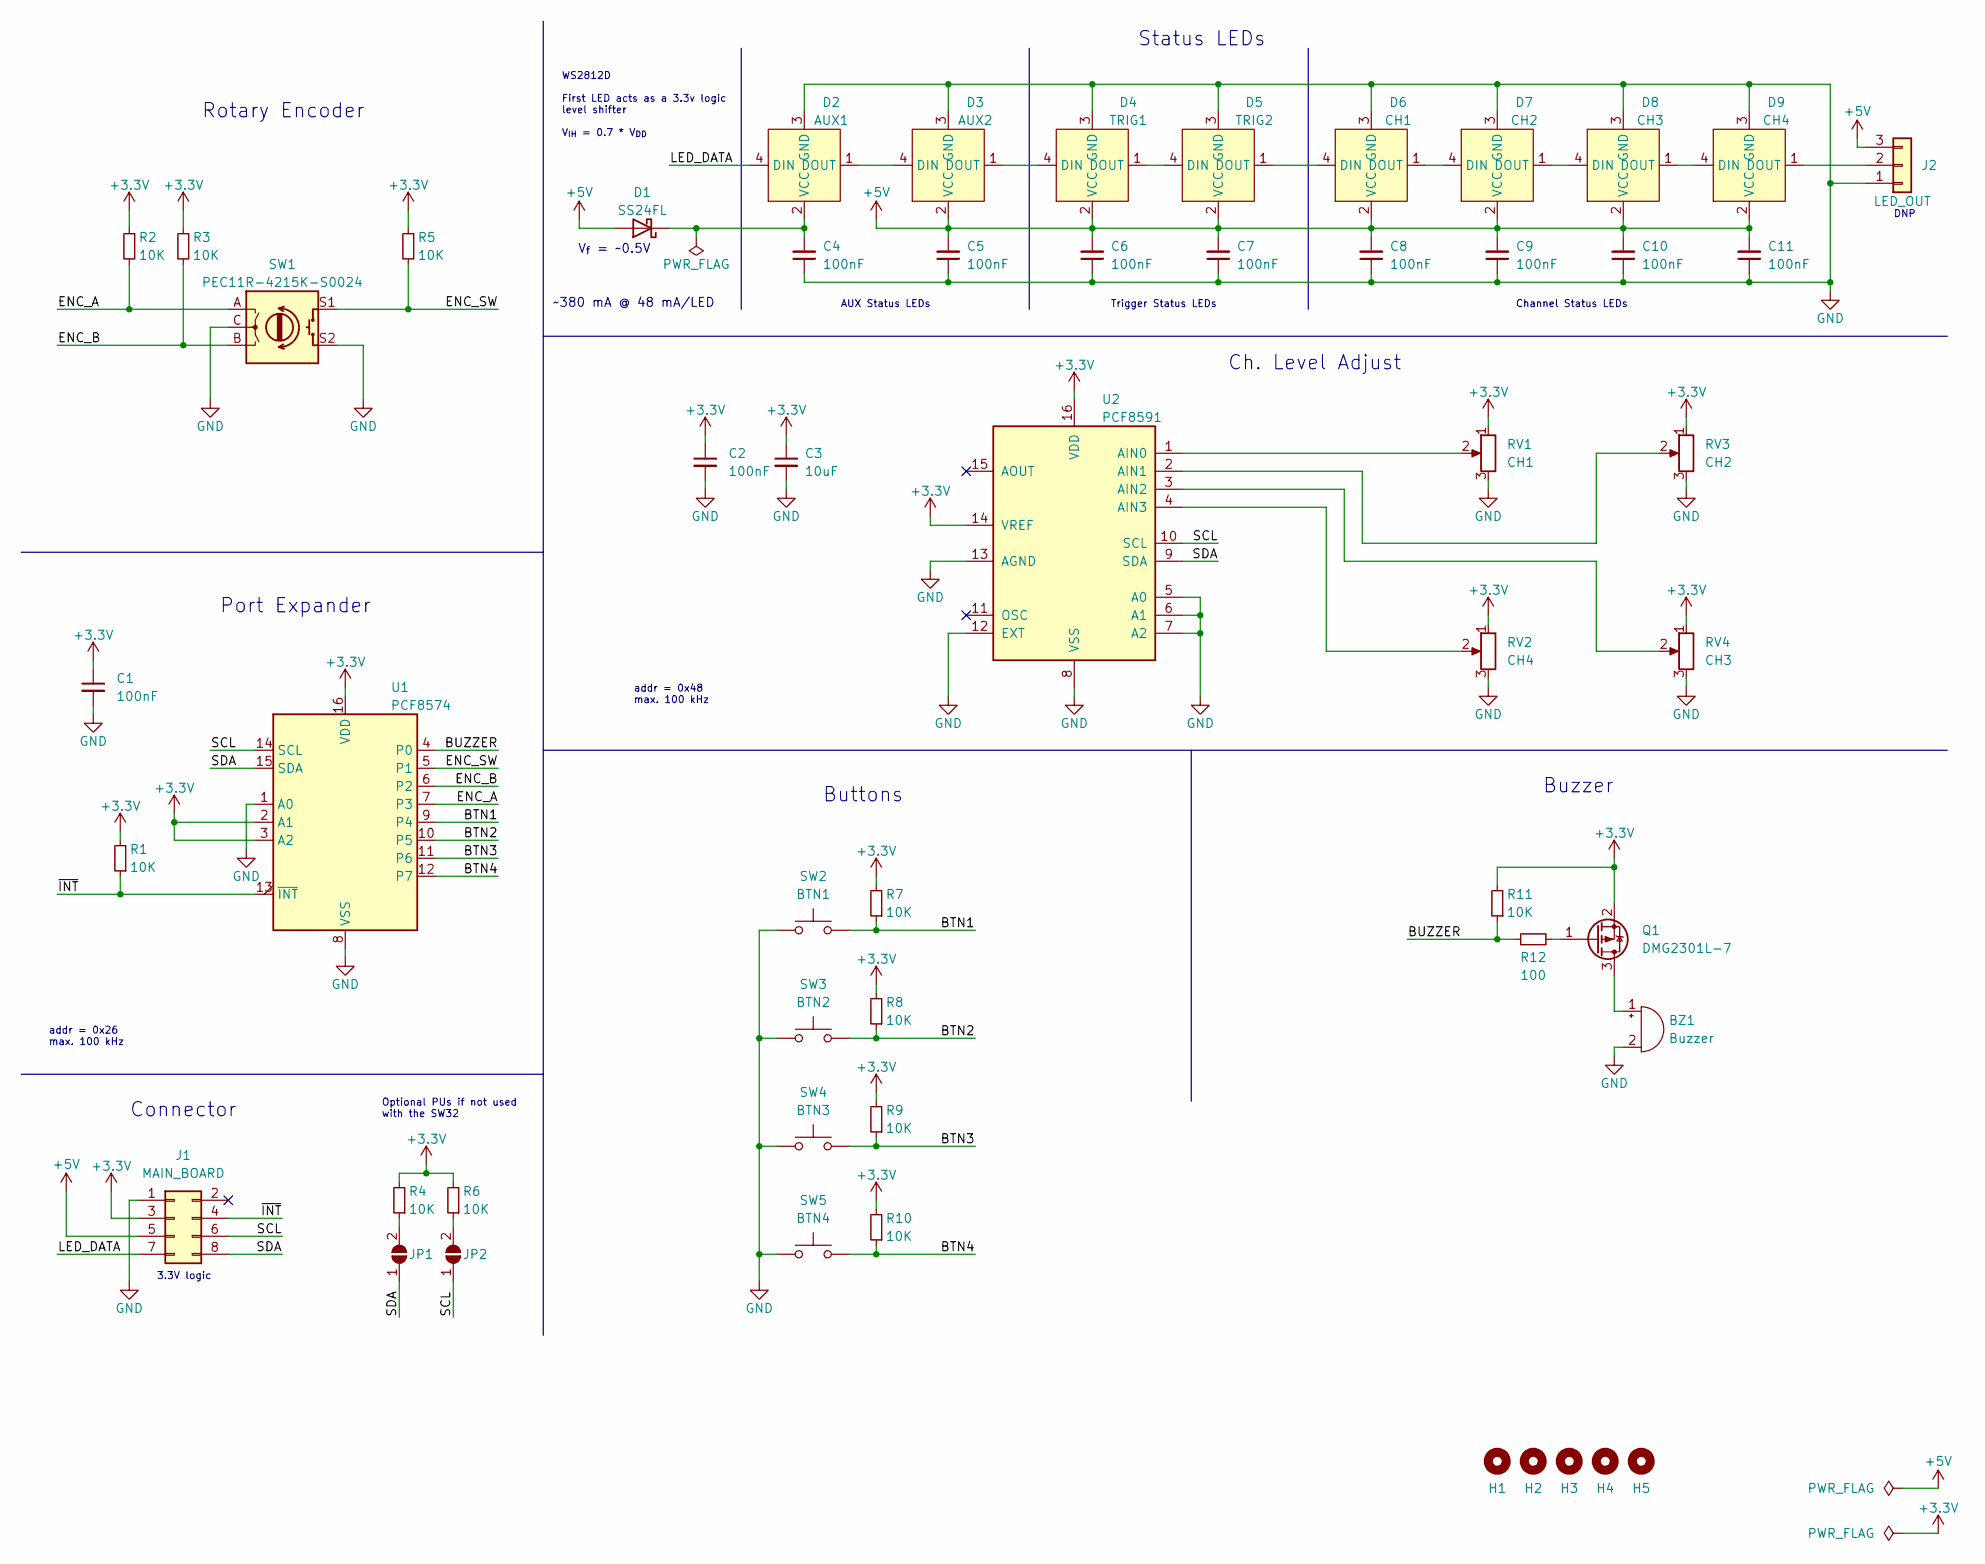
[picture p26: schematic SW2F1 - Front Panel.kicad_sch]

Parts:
BZ1: Buzzer; Buzzer_12x9.5RM7.6; MPN IE122303-1; MOUSER 497-IE122303-1
C1, C2, C4, C5, C6, C7, C8, C9, C10, C11: 100nF; C_0603_1608Metric; MPN CL10B104KB8NNNC; LCSC C1591
C3: 10uF; C_0603_1608Metric; MPN CL10A106MA8NRNC; LCSC C96446
D1: SS24FL; D_SOD-123F; MPN SS24FL; MOUSER 512-SS24FL
D2: AUX1; WS2812D-F5; MPN WS2812D-F5; LCSC C190565
D3: AUX2; WS2812D-F5; MPN WS2812D-F5; LCSC C190565
D4: TRIG1; WS2812D-F5; MPN WS2812D-F5; LCSC C190565
D5: TRIG2; WS2812D-F5; MPN WS2812D-F5; LCSC C190565
D6: CH1; WS2812D-F5; MPN WS2812D-F5; LCSC C190565
D7: CH2; WS2812D-F5; MPN WS2812D-F5; LCSC C190565
D8: CH3; WS2812D-F5; MPN WS2812D-F5; LCSC C190565
D9: CH4; WS2812D-F5; MPN WS2812D-F5; LCSC C190565
H1, H2, H3, H4, H5: MountingHole; MountingHole_2.2mm_M2
J1: MAIN_BOARD; IDC-Header_2x04_P2.54mm_Vertical
J2: LED_OUT; PinHeader_1x03_P2.54mm_Vertical
JP1, JP2: SolderJumper_2_Open; SolderJumper-2_P1.3mm_Open_RoundedPad1.0x1.5mm
Q1: DMG2301L-7; SOT-23; MPN DMG2301L-7; LCSC C102619
R1, R2, R3, R4, R5, R6, R7, R8, R9, R10, R11: 10K; R_0603_1608Metric; MPN RC0603FR-0710KL; LCSC C98220
R12: 100; R_0603_1608Metric; MPN RC0603FR-07100RL; MOUSER 603-RC0603FR-07100RL
RV1: CH1; Potentiometer_Bourns_PTV09A-1_Single_Vertical; MPN PTV09A-4020S-B103
RV2: CH4; Potentiometer_Bourns_PTV09A-1_Single_Vertical; MPN PTV09A-4020S-B103
RV3: CH2; Potentiometer_Bourns_PTV09A-1_Single_Vertical; MPN PTV09A-4020S-B103
RV4: CH3; Potentiometer_Bourns_PTV09A-1_Single_Vertical; MPN PTV09A-4020S-B103
SW1: PEC11R-4215K-S0024; Rotary_Encoder_Switched_PEC11R; MPN PEC11R-4215K-S0024
SW2: BTN1; D6C; MPN D6C90F2LFS; MOUSER 611-D6C90F2LFS
SW3: BTN2; D6C; MPN D6C90F2LFS; MOUSER 611-D6C90F2LFS
SW4: BTN3; D6C; MPN D6C90F2LFS; MOUSER 611-D6C90F2LFS
SW5: BTN4; D6C; MPN D6C90F2LFS; MOUSER 611-D6C90F2LFS
U1: PCF8574; SOIC-16W_7.5x10.3mm_P1.27mm; MPN PCF8574T/3,512; LCSC C1522621
U2: PCF8591; SOIC-16W_7.5x10.3mm_P1.27mm; MPN PCF8591T/2,518; MOUSER 771-PCF8591TD-T

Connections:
+3.3V: C1.1, C2.1, C3.1, J1.3, Q1.2 (S), R1.2, R2.1, R3.1, R4.2, R5.1, R6.2, R7.2, R8.2, R9.2, R10.2, R11.2, RV1.1, RV2.1, RV3.1, RV4.1, U1.2 (A1), U1.3 (A2), U1.16 (VDD), U2.14 (VREF), U2.16 (VDD); also elsewhere on the board
+5V: C5.2, C6.2, C7.2, C8.2, C9.2, C10.2, C11.2, D1.2 (A), D3.2 (VCC), D4.2 (VCC), D5.2 (VCC), D6.2 (VCC), D7.2 (VCC), D8.2 (VCC), D9.2 (VCC), J1.5, J2.3
/BTN1: R7.1, SW2.2, U1.9 (P4)
/BTN2: R8.1, SW3.2, U1.10 (P5); also elsewhere on the board
/BTN3: R9.1, SW4.2, U1.11 (P6)
/BTN4: R10.1, SW5.2, U1.12 (P7)
/BUZZER: R11.1, R12.1, U1.4 (P0)
/ENC_A: R2.2, SW1.A, U1.7 (P3)
/ENC_B: R3.2, SW1.B, U1.6 (P2)
/ENC_SW: R5.2, SW1.S1, U1.5 (P1)
/LED_DATA: D2.4 (DIN), J1.7
/SCL: J1.6, JP2.1 (A), U1.14 (SCL), U2.10 (SCL)
/SDA: J1.8, JP1.1 (A), U1.15 (SDA), U2.9 (SDA)
/~INT: J1.4, R1.1, U1.13 (~INT)
GND: BZ1.2 (+), C1.2, C2.2, C3.2, C4.1, C5.1, C6.1, C7.1, C8.1, C9.1, C10.1, C11.1, D2.3 (GND), D3.3 (GND), D4.3 (GND), D5.3 (GND), D6.3 (GND), D7.3 (GND), D8.3 (GND), D9.3 (GND), J1.1, J2.1, RV1.3, RV2.3, RV3.3, RV4.3, SW1.C, SW1.S2, SW2.1, SW3.1, SW4.1, SW5.1, U1.1 (A0), U1.8 (VSS), U2.5 (A0), U2.6 (A1), U2.7 (A2), U2.8 (VSS), U2.12 (EXT), U2.13 (AGND)
unnamed: BZ1.1 (-), Q1.3 (D)
unnamed: C4.2, D1.1 (K), D2.2 (VCC)
unnamed: D2.1 (DOUT), D3.4 (DIN)
unnamed: D3.1 (DOUT), D4.4 (DIN)
unnamed: D4.1 (DOUT), D5.4 (DIN)
unnamed: D5.1 (DOUT), D6.4 (DIN)
unnamed: D6.1 (DOUT), D7.4 (DIN)
unnamed: D7.1 (DOUT), D8.4 (DIN)
unnamed: D8.1 (DOUT), D9.4 (DIN)
unnamed: D9.1 (DOUT), J2.2
unnamed: JP1.2 (B), R4.1
unnamed: JP2.2 (B), R6.1
unnamed: Q1.1 (G), R12.2
unnamed: RV1.2, U2.1 (AIN0)
unnamed: RV2.2, U2.4 (AIN3)
unnamed: RV3.2, U2.2 (AIN1)
unnamed: RV4.2, U2.3 (AIN2)

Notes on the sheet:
~380 mA @ 48 mA/LED
Channel Status LEDs
AUX Status LEDs
Ch. Level Adjust
3.3V logic
Port Expander
Buttons
DNP
Status LEDs
Optional PUs if not used with the SW32
addr = 0x48 max. 100 kHz
V_{f} = ~0.5V
Trigger Status LEDs
Buzzer
Rotary Encoder
Connector
addr = 0x26 max. 100 kHz
WS2812D First LED acts as a 3.3v logic level shifter V_{IH} = 0.7 * V_{DD}

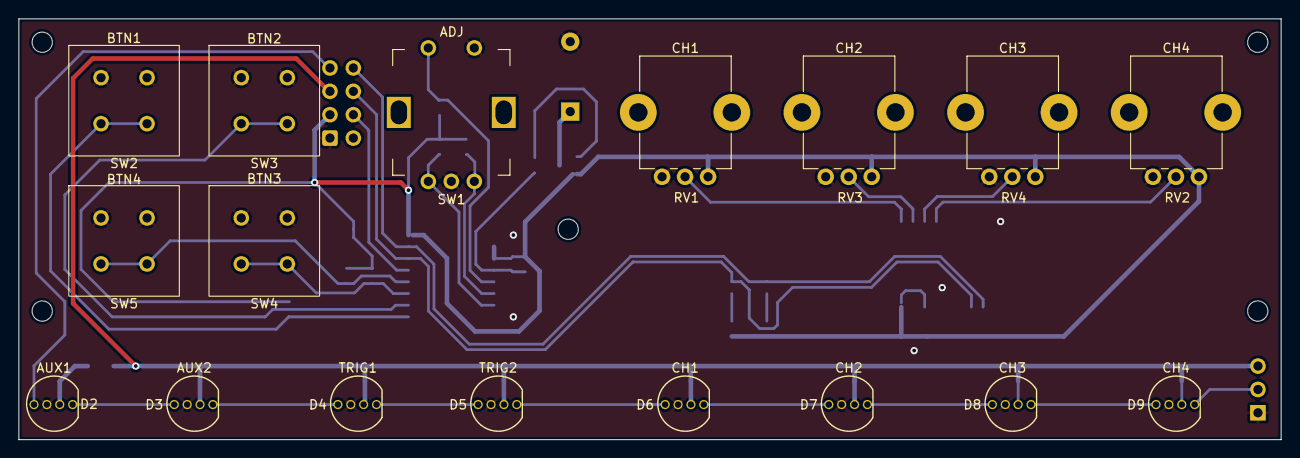
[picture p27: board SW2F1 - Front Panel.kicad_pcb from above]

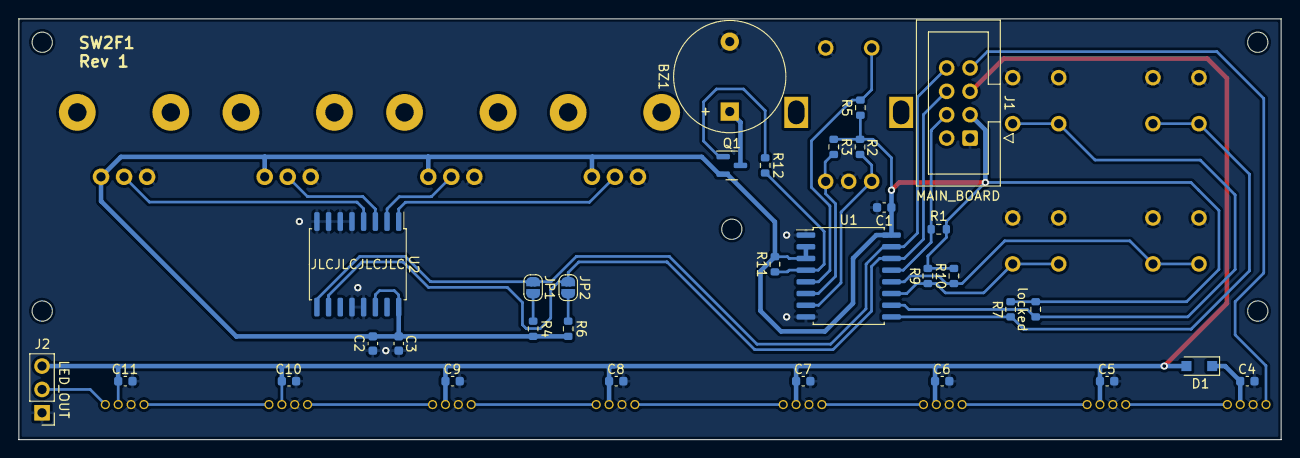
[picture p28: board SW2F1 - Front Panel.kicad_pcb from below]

Board: 2 copper layers, 137.2 x 45.7 mm, 54 parts (32 on the bottom side), 32 nets.

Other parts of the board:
locked: 10K; R_0603_1608Metric

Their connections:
+3.3V: locked.2; also elsewhere on the board
/BTN2: locked.1; also elsewhere on the board

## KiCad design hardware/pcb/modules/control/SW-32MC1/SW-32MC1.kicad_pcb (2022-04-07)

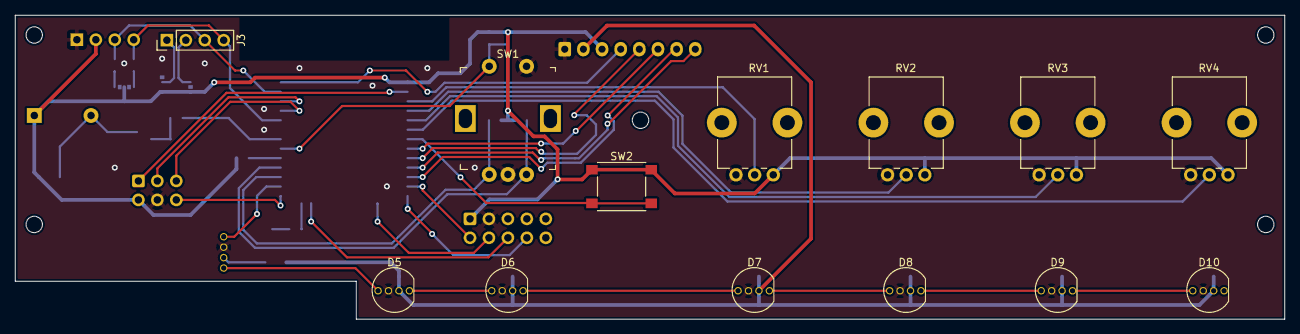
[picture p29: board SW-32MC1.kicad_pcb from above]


Board: 2 copper layers, 170.2 x 40.7 mm, 53 parts (35 on the bottom side), 44 nets.

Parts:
BZ1: Buzzer; Buzzer_12x9.5RM7.6
C1, C2, C5: 10nF; C_0603_1608Metric
C3: 10uF; C_0603_1608Metric
C4, C6, C7, C8, C9, C10, C11: 100nF; C_0603_1608Metric
D1: LED; LED_0603_1608Metric
D2: D_Small; D_SOD-123F
D3: D; D_SOD-123F
D4, D5, D6, D7, D8, D9, D10: WS2812D; WS2812D-F5
H1, H2, H3, H4, H5: MountingHole; MountingHole_2.2mm_M2
J1: JTAG; IDC-Header_2x05_P2.54mm_Vertical
J2: ESPFlash; IDC-Header_2x03_P2.54mm_Vertical
J3: OLED; OLED_I2C_1.3
J4: FP_IO; JST_XH_B8B-XH-A_1x08_P2.50mm_Vertical
J5: I2C; PinHeader_1x04_P2.54mm_Vertical
JP1, JP2: SolderJumper_3_Bridged12; SolderJumper-3_P1.3mm_Bridged12_Pad1.0x1.5mm_NumberLabels
JP4: SolderJumper_3_Bridged123; SolderJumper-3_P1.3mm_Bridged123_Pad1.0x1.5mm_NumberLabels
Q1: Q_NMOS_DGS; SOT-23
R1, R2, R4, R10, R12: 10K; R_0603_1608Metric
R3, R5: 10k; R_0603_1608Metric
R8, R11: 2.7K; R_0603_1608Metric
R9: 10; R_0603_1608Metric
RV1, RV2, RV3, RV4: 20K; Potentiometer_Bourns_PTV09A-1_Single_Vertical
SW1: PEC11R-4225F-S0024; Rotary_Encoder_Switched_PEC11R
SW2: DNP; SW_Push_1P1T_NO_6x6mm_H9.5mm
U1: ESP32-WROOM-32D; ESP32-WROOM-32

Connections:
+3V3: BZ1.1 (-), C3.1, C4.1, D2.1 (K), J1.1, J2.2, J4.3, J5.2, JP1.1 (A), JP2.3 (B), JP4.2 (C), R1.1, R2.1, R3.2, R4.1, RV1.1, RV2.1, RV3.1, RV4.1, SW2.1, U1.2 (VDD)
+5V: C6.2, C7.2, C8.2, C9.2, C10.2, C11.2, D3.2 (A), D5.2 (VCC), D6.2 (VCC), D7.2 (VCC), D8.2 (VCC), D9.2 (VCC), D10.2 (VCC), J4.2
/BUZZER: R9.1, U1.31 (IO19)
/EN: J2.1, U1.3 (EN)
/ENC_A: C2.1, R2.2, SW1.A, U1.27 (IO16)
/ENC_B: C1.1, R1.2, SW1.B, U1.28 (IO17)
/ENC_SW: C5.1, R4.2, SW1.S1, U1.30 (IO18)
/IO0: J2.6, U1.25 (IO0)
/IO2: R5.1, U1.24 (IO2)
/IO5: R3.1, U1.29 (IO5)
/LED_DATA: D4.4 (DIN), U1.26 (IO4)
/LINE_LEFT: J4.7, U1.12 (IO27)
/LINE_RIGHT: J4.6, U1.9 (IO33)
/LVL_A: RV1.2, U1.4 (SENSOR_VP)
/LVL_B: RV2.2, U1.5 (SENSOR_VN)
/LVL_C: RV3.2, U1.6 (IO34)
/LVL_D: RV4.2, U1.7 (IO35)
/MAIN_SCL: J4.4, U1.37 (IO23)
/MAIN_SDA: J4.5, U1.10 (IO25)
/MIC: J4.8, U1.11 (IO26)
/MTCK: J1.4, U1.16 (IO13)
/MTDI: J1.8, U1.14 (IO12)
/MTDO: J1.6, U1.23 (IO15)
/MTMS: J1.2, U1.13 (IO14)
/RXD: J2.5, U1.34 (RXD0/IO3)
/SCL: J3.3 (SCL), J5.3, R8.2, U1.36 (IO22)
/SDA: J3.4 (SDA), J5.4, R11.2, U1.33 (IO21)
/SW1: R12.1, SW2.2, U1.8 (IO32)
/TXD: J2.3, U1.35 (TXD0/IO1)
GND: C1.2, C2.2, C3.2, C4.2, C5.2, C6.1, C7.1, C8.1, C9.1, C10.1, C11.1, D1.1 (K), D4.3 (GND), D5.3 (GND), D6.3 (GND), D7.3 (GND), D8.3 (GND), D9.3 (GND), D10.3 (GND), J1.3, J2.4, J4.1, J5.1, JP1.3 (B), JP2.1 (A), Q1.1 (S), R10.2, R12.2, RV1.3, RV2.3, RV3.3, RV4.3, SW1.C, SW1.S2, U1.1 (GND), U1.15 (GND), U1.38 (GND), U1.39 (GND)
unnamed: BZ1.2 (+), D2.2 (A), Q1.3 (D)
unnamed: D1.2 (A), R5.2
unnamed: D3.1 (K), D4.2 (VCC)
unnamed: D4.1 (DOUT), D5.4 (DIN)
unnamed: D5.1 (DOUT), D6.4 (DIN)
unnamed: D6.1 (DOUT), D7.4 (DIN)
unnamed: D7.1 (DOUT), D8.4 (DIN)
unnamed: D8.1 (DOUT), D9.4 (DIN)
unnamed: D9.1 (DOUT), D10.4 (DIN)
unnamed: J3.1 (GND), JP2.2 (C)
unnamed: J3.2 (VCC), JP1.2 (C)
unnamed: JP4.1 (A), R11.1
unnamed: JP4.3 (B), R8.1
unnamed: Q1.2 (G), R9.2, R10.1

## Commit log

2022-01-30 add initial SW-3221 design
    [SW-3221.kicad_pcb, SW-3221.kicad_sch, controller.kicad_sch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]
2022-01-30 use io5 for encoder switch
    [SW-3221.kicad_sch, controller.kicad_sch, input.kicad_sch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]
2022-01-31 update part numbers
    [SW-3211M.kicad_pcb, SW-3211M.kicad_sch]
2022-02-02 make SW-3240 modular
    [SW-3240.kicad_pcb, SW-3240.kicad_sch, controller.kicad_sch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]
2022-02-02 add basic audio module
    [SW-32MA1.kicad_pcb, SW-32MA1.kicad_sch]
2022-02-02 add basic front panel module
    [SW-32MC1.kicad_pcb, SW-32MC1.kicad_sch]
2022-02-02 add basic output board
    [SW-32MO10.kicad_pcb, SW-32MO10.kicad_sch]
2022-02-02 update dru
    [SW-3240.kicad_pcb, SW-32MA1.kicad_pcb, SW-32MC1.kicad_pcb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]
2022-02-03 split dual esp32 modules
    [SW-3240.kicad_sch, controller.kicad_sch, power.kicad_sch]
2022-02-04 add main mcu to front panel
    [SW-32MC1.kicad_sch]
2022-02-04 add schematic pdfs
2022-02-04 fix footprint pin mismatch
    [SW-3240.kicad_sch, power.kicad_sch]
2022-02-04 update pdf
    [SW-32MA1.kicad_sch, SW-32MC1.kicad_sch, SW-32MO10.kicad_sch]
2022-02-06 many changes
    [SW-3240.kicad_pcb, SW-3240.kicad_sch, SW-32MC1.kicad_sch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]
2022-02-06 add schematic link shortcuts
2022-02-07 use 5v for front panel connector
    [SW-3240.kicad_sch, SW-32MC1.kicad_sch, power.kicad_sch]
2022-02-22 use atmega328pb for main board
    [SW-3240.kicad_sch, power.kicad_sch]
2022-04-07 major changes
    [SW-3240.kicad_pcb, SW-3240.kicad_sch, SW-32MA1.kicad_pcb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]
2022-04-08 excluded bom items
2022-06-29 fix comments
    [SW-324.csv, SW-324.kicad_pcb, SW-324.kicad_sch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]
2022-06-29 use baremetal pico
2022-10-09 redesign / project restructure
    [SW-324.csv, SW-324.kicad_pcb, SW-324.kicad_sch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]
2022-10-14 fix inconsistencies
    [SW3F1 - Front Panel.kicad_sch]
2022-10-14 finalize driver board
    [SW3X1 - Driver Board.csv, SW3X1 - Driver Board.kicad_pcb, SW3X1 - Driver Board.kicad_sch]
2022-10-14 fix wrong ADC footprint
    [SW3X1 - Driver Board.csv, SW3X1 - Driver Board.kicad_pcb, SW3X1 - Driver Board.kicad_sch]
2022-10-22 align modules on the same 0.1" grid
    [SW3X1 - Driver Board.kicad_pcb]
2022-11-05 use ESP32
    [SW32 - Base Board.csv, SW32 - Base Board.kicad_pcb, SW32 - Base Board.kicad_sch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]
2022-11-07 misc. cleanup
    [SW32 - Base Board.kicad_pcb, SW32 - Base Board.kicad_sch, SW3F1 - Front Panel.kicad_pcb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]
2022-11-07 add gerbers
2022-11-08 add SW3O2
    [SW3O2.csv, SW3O2.kicad_pcb, SW3O2.kicad_sch]
2022-11-10 add optional I2C pullups
    [SW3F1 - Front Panel.kicad_pcb, SW3F1 - Front Panel.kicad_sch]
2022-11-13 add cap
    [SW32 - Base Board.csv, SW32 - Base Board.kicad_pcb, SW32 - Base Board.kicad_sch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]
2022-11-14 rev 1
    [SW3F1 - Front Panel.csv, SW3O1.csv, SW3X1 - Driver Board.kicad_pcb]
2022-12-18 add pcb images
2022-12-19 update MPN for rotary encoder
    [SW3F1 - Front Panel.csv, SW3F1 - Front Panel.kicad_pcb, SW3F1 - Front Panel.kicad_sch]
2022-12-19 update MPN for pots
    [SW3F1 - Front Panel.csv, SW3F1 - Front Panel.kicad_pcb, SW3F1 - Front Panel.kicad_sch]
2022-12-20 add front cover
    [6x4mm_4-pin_led_spacer.stl, SW3C1 - Front Cover-Edge_Cuts.dxf, SW3C1 - Front Cover.kicad_pcb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]
2022-12-20 add front panel pcb images
2022-12-20 cleanup silkscreen
    [SW3C1 - Front Cover.kicad_pcb]
2022-12-21 update tolerances
    [SW3C1 - Front Cover-Edge_Cuts.dxf, SW3C1 - Front Cover.kicad_pcb, SW3C1 - Front Cover.stl]
2022-12-21 fix auto program
    [SW32 - Base Board.csv, SW32 - Base Board.kicad_pcb, SW32 - Base Board.kicad_sch]
2022-12-21 increase spoke width for driver header
    [SW32 - Base Board.kicad_pcb]
2022-12-21 simplify bom - use SS24FL
    [SW3F1 - Front Panel.csv, SW3F1 - Front Panel.kicad_pcb, SW3F1 - Front Panel.kicad_sch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]
2022-12-21 add USB marker for pico
    [SW3X1 - Driver Board.kicad_pcb]
2022-12-22 add power led
    [SW32 - Base Board.csv, SW32 - Base Board.kicad_pcb, SW32 - Base Board.kicad_sch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]
2022-12-22 fix incorrect MPN
    [SW3X1 - Driver Board.csv, SW3X1 - Driver Board.kicad_pcb, SW3X1 - Driver Board.kicad_sch]
2023-01-14 move silkscreen from case edge
    [SW3C1 - Front Cover.kicad_pcb]
2023-06-19 add SW2E1
    [SW2E1.kicad_pcb, SW2E1.kicad_sch]
